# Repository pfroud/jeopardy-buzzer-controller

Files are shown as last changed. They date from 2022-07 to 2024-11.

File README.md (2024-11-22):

# Jeopardy buzzer controller

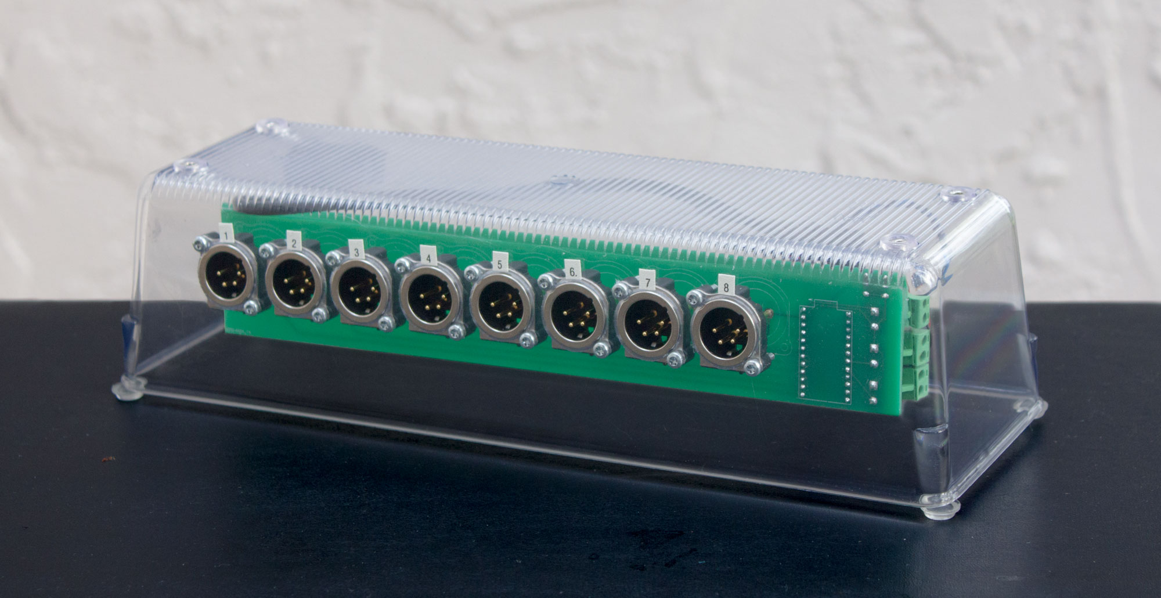
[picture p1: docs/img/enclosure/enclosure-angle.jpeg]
photo of enclosure


## About

For use with my [Jeopardy software](https://github.com/pfroud/jeopardy).

This device uses an Arduino to emulate a USB HID keyboard (like a QWERTY keyboard not a music keyboard). Instead of normal keyboard keys, the inputs come from rugged metal footswitches on long cables.

The sole purpose of this device is to convert physical button presses into USB HID keystrokes. It cannot tell which person buzzed first for a question, for example. All of that logic is done by software running on the host PC.

The PCB was designed using KiCad version 6 and fabricated by JLCPCB.

## Parts

The two most interesting parts are:

* [Sparkfun Pro Micro](https://www.sparkfun.com/products/12640) (not Mini, not Nano)
    * Informally called "Arduino Pro Micro" but it's actually a Sparkfun product which is Arduino-compatible.
    * To learn about the software running on the Arduino, see the [Arduino directory](Arduino).
* [XLR receptacle NC4MBV](https://www.neutrik.com/en/product/nc4mbv-1) to connect the buzzers.
    * To learn more, go to the "XLR connectors" section in this document.

Other parts:

* [12-pin female headers](https://www.aliexpress.us/item/2255801012106911.html) to hold the Arduino.
    * The Arduino could instead be soldered directly to the PCB if you're feeling confident.
* A toggle switch to enable/disable the Arduino software.
    * Lets you turn the buzzers off without unplugging the USB cable.
* [Panel-mount LED lights](https://www.aliexpress.com/item/3256803816108154.html) to indicate when it's powered and enabled.
* [2-pin pluggable terminal blocks](https://www.aliexpress.us/item/2251832631116561.html) to connect the toggle switch and indicator LEDs to the PCB.
* A 6mm tactile pushbutton to reset the Arduino.
    * The Pro Micro does not have a built-in reset button.

Then everything gets assembled into an [enclosure](docs/enclosure.md).

## Buzzers

On the Jeopardy TV show each contestant holds a thumb-operated buzzer ([source](https://www.jeopardy.com/jbuzz/behind-scenes/how-does-jeopardy-buzzer-work)).

My game has teams instead of individual players, so the buzzers rest on a table for access by all team members. I got rugged metal footswitches to withstand being slammed when someone thinks of an answer.

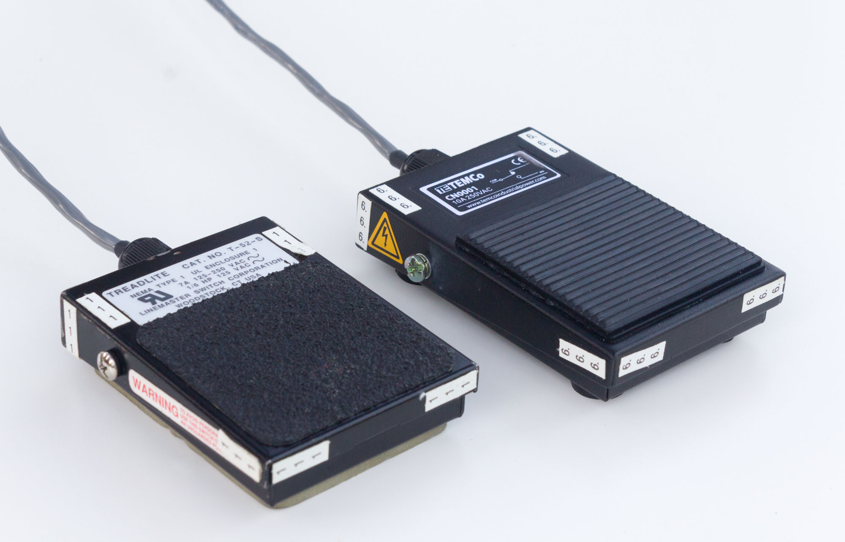
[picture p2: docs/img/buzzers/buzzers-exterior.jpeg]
Photo of two footswitches used as buzzers


I started with Treadlite footswitches from at HSC Electronics (RIP) then got some TEMCo ones from [eBay](https://www.ebay.com/itm/372481343124).

On each footswitch I had to grind down the metal housing a little to fit a [PG7 cord grip](https://www.ebay.com/itm/222727122407). (PG stands for [Panzergewinde](https://en.wikipedia.org/wiki/Panzergewinde) which is an old German thread standard inexplicably still in use.)

The Treadlite model (below left) has a seemingly-custom switch mechanism inside, while the TEMCo model (below right) has a standard limit switch. The Treadlite ones originally come with *two* switches mounted at different heights but I removed the lower ones. The cable I used has a foil shield so I connected the drain wire to the metal housing for fun.

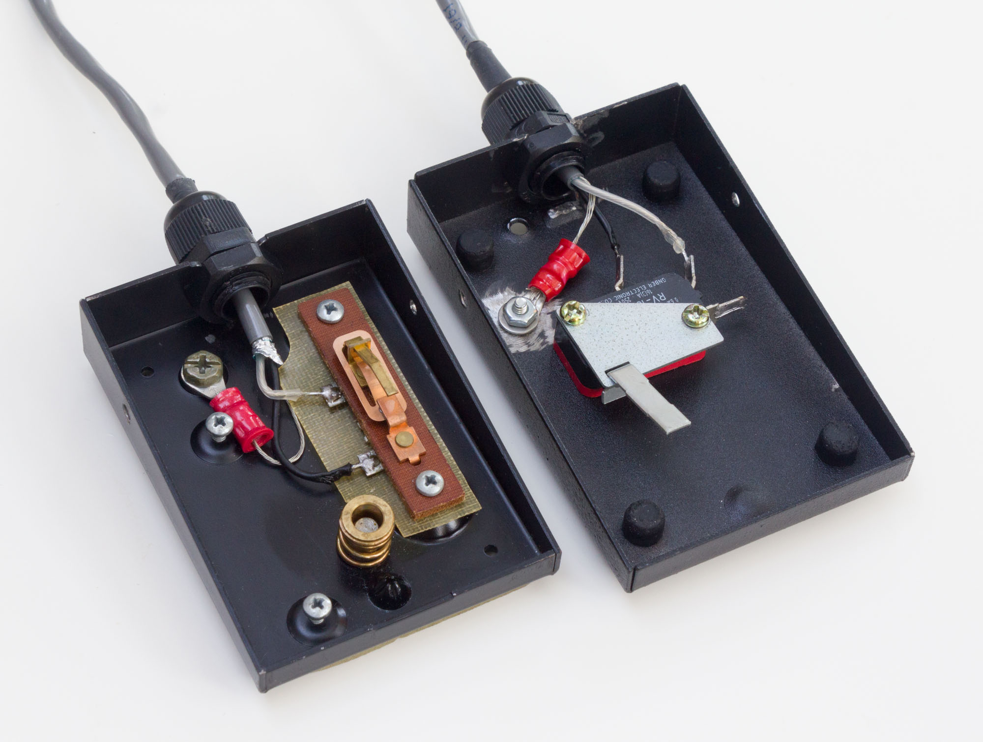
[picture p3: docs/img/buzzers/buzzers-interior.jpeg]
Photo of two footswitches with the tops removed to show the switches and wiring inside


Eight buzzers are supported although I rarely use more than six.

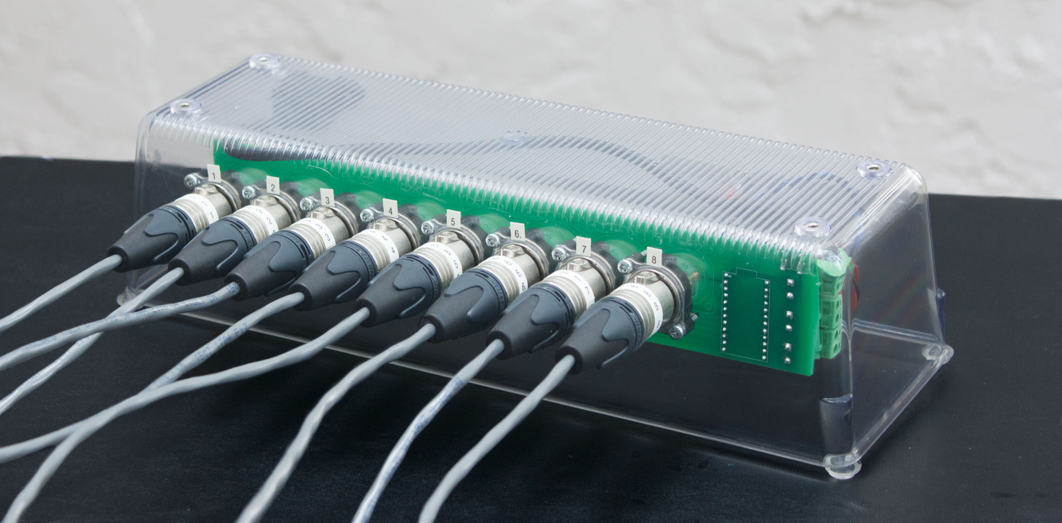
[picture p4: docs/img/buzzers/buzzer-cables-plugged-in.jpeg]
Photo of controller with eight buzzer cables plugged in


## Known bugs & future work

### PCB design

* There is no input protection on the Arduino pins.
* The trace length between the Arduino and XLR connector is different for each connector.

### Does using an HID keyboard for this make any sense??

Not really. The original scope of my [Jeopardy project](https://github.com/pfroud/jeopardy) was software only. The hardware buzzers have been gradually developed as needed. Want to keep it simple!

See docs/dont-use-a-HID-keyboard.md.

### Issues with the XLR connectors

XLR connectors are usually used in professional audio and stage lighting, so they are overkill for this application. I wanted locking connectors and found these in surplus.

#### Wasted pins

Only two out of four pins are used. In the future, the spare pins could be used for lighting or some other new feature. An overwhelming number of two-pin locking connectors are available.

#### Polarity

The polarity of the XLR connectors should be reversed.

Neutrik makes four types of 4-pin XLR connectors. Look at the table below for a visual aid.

The receptacles on the controller are male (top left, NC4MBV) which allows fingers to touch the pins, exposing the Arduino to static electricity.

Meanwhile the connectors on the buzzer cables are female (bottom right, NC4FXX). The recessed pins prevent fingers touching them, but that protection isn't needed because the buzzers contain only passive switches.

The controller should use female receptacles, and the buzzers should use male cable connectors.

<table>
<tr>
    <td></td>
    <td align="center">Male</td>
    <td align="center">Female</td>
</tr>
<tr>
    <td>Receptacle</td>
    <td align="center">
        <a href="https://www.neutrik.us/en-us/product/nc4mbv-1">
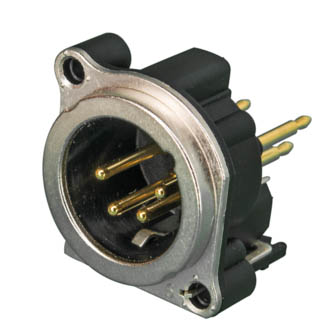
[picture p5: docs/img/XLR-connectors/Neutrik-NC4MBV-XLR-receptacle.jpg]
Neutrik NC4MBV XLR receptacle
            
            <br>
            NC4MBV
        </a>
    </td>
    <td align="center">
        <a href="https://www.neutrik.us/en-us/product/nc4fbv">
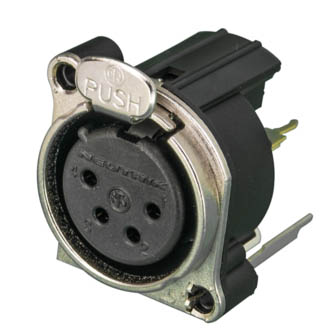
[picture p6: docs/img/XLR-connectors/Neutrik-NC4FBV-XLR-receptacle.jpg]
Neutrik NC4FBV XLR receptacle
            
            <br>
            NC4FBV
        </a>
    </td>
</tr>
<tr>
    <td>Cable connector</td>
    <td align="center">
        <a href="https://www.neutrik.us/en-us/product/nc4mxx">
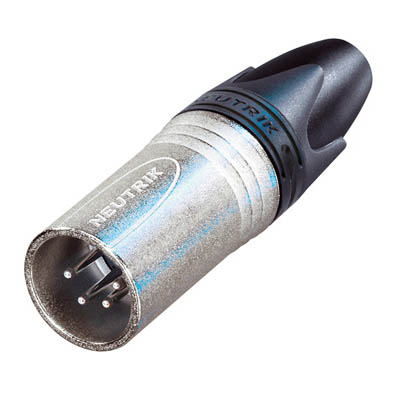
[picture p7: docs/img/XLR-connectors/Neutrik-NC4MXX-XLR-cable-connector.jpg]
Neutrik NC4MXX XLR cable connector
            
            <br>
            NC4MXX
        </a>
    </td>
    <td align="center">
        <a href="https://www.neutrik.us/en-us/product/nc4fxx">
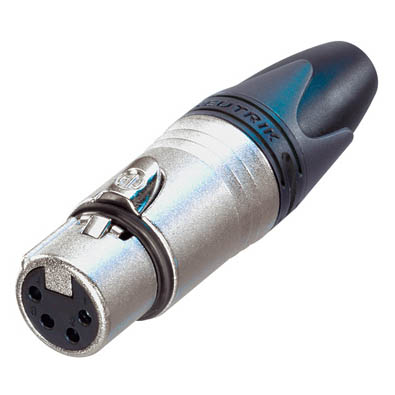
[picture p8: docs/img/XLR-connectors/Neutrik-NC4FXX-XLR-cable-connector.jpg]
Neutrik NC4FXX XLR cable connector
            
            <br>
            NC4FXX
        </a>
    </td>
</tr>
</table>

## Previous versions of my Jeopardy buzzer controller

I made my first Jeopardy buzzer controller in 2018. It used the the PCB from an off-the-shelf USB keyboard (a QWERTY keyboard not a music keyboard) to convert physical button presses into USB HID keystrokes.

Inside the case of a broken power tool battery charger was a tangle of wires and Wago lever nuts. I used barrel jacks intended for DC power to connect the buzzers because they were easily available. This worked acceptably well but looked crazy:

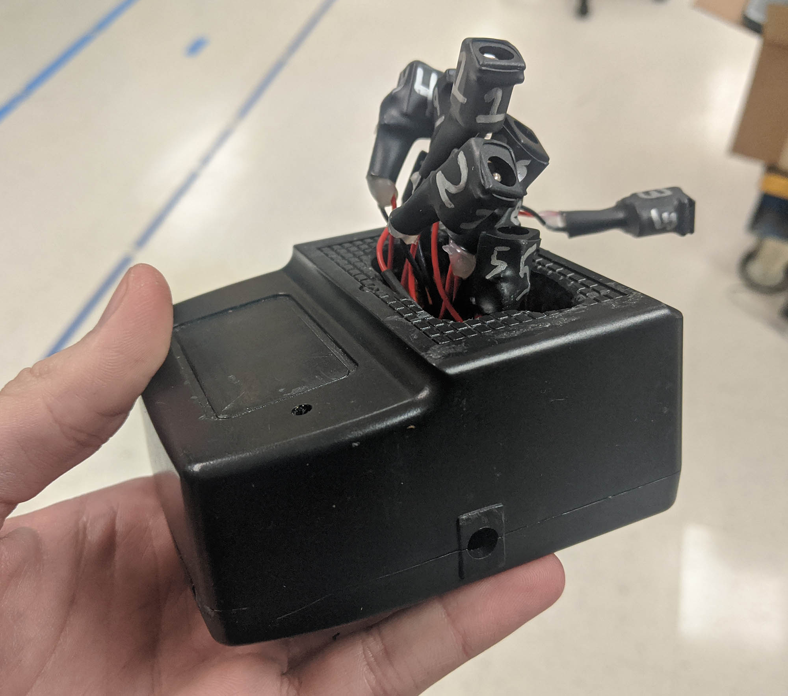
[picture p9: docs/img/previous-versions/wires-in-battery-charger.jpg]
Photo of several wires coming out of a handheld black plastic box


In 2020 re-did the enclosure and wiring but kept using barrel jacks:

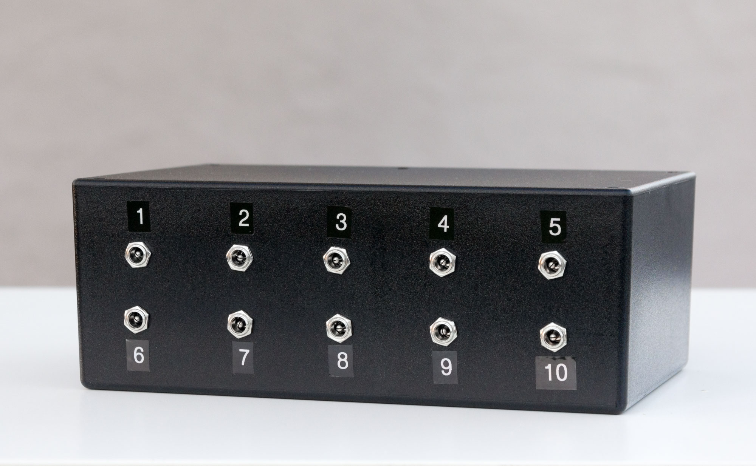
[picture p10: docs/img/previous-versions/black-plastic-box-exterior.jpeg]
Photo of the outside of a black plastic box with ten connectors on the front


Inside the new enclosure, I upgraded to a prototype board and pluggable wire-to-board connectors. The USB keyboard PCB is visible on the left:

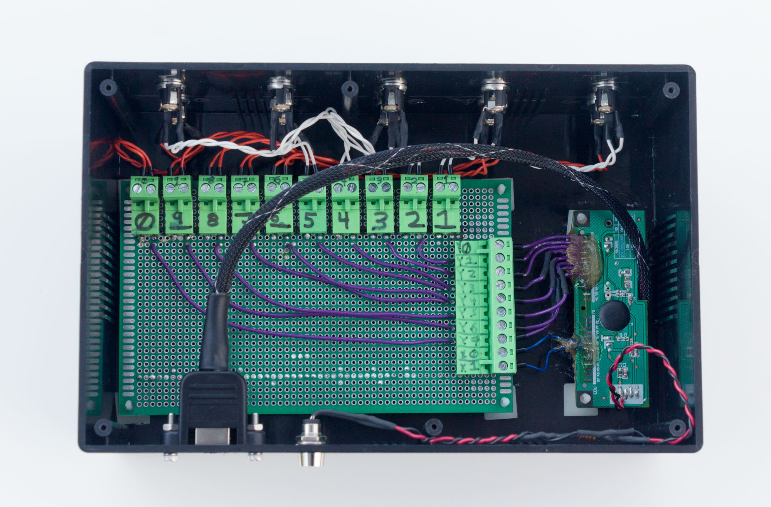
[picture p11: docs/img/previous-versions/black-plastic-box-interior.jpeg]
Photo of the inside of the black plastic box showing two circuit boards and a bunch of wires and connectors


In 2022 I re-did the whole thing with a custom PCB and Arduino (which is this repository).

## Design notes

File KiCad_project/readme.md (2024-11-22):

# KiCad project

Pictures of the PCB:

<table>
<tr>
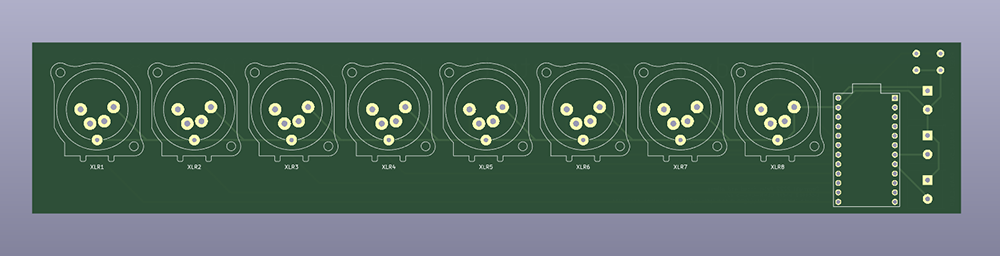
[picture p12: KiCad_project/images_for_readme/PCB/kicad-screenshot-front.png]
Screenshot of front of PCB in KiCad
<td></td>
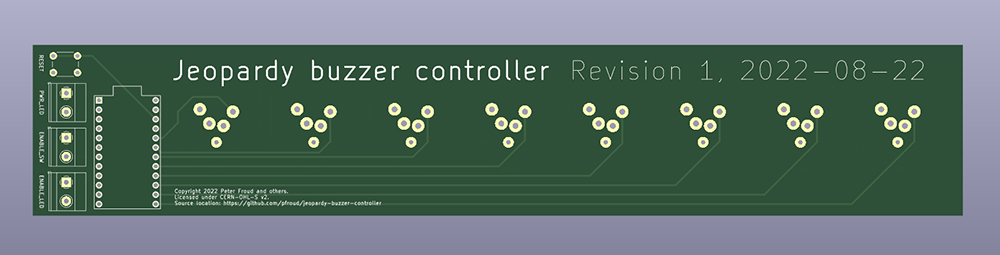
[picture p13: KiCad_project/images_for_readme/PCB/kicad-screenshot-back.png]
Screenshot of back of PCB in KiCad
<td></td>
</tr>
<tr>
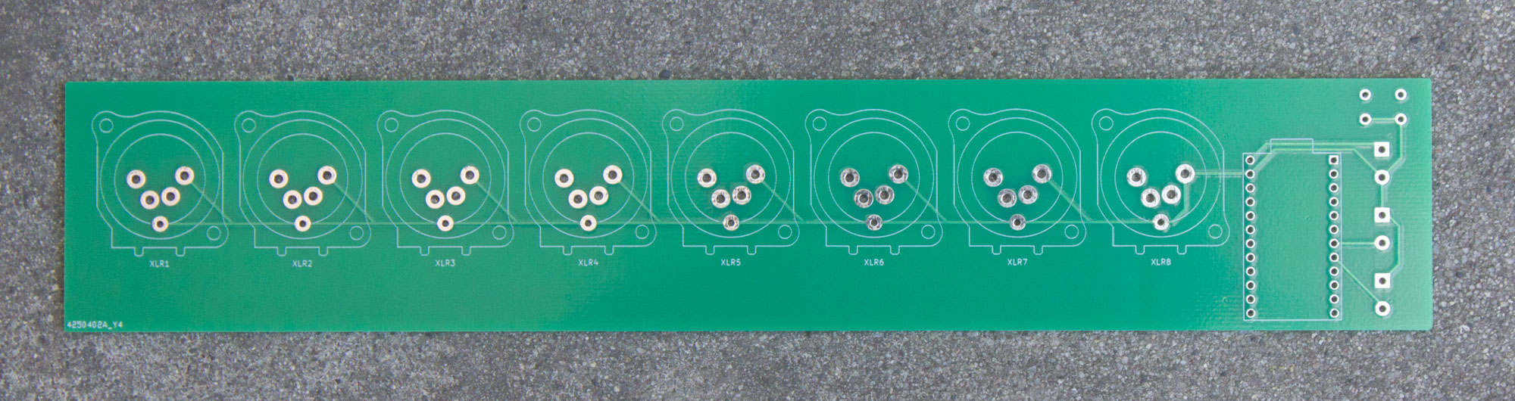
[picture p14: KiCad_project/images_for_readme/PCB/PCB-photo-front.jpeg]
Photo of front of PCB
<td></td>
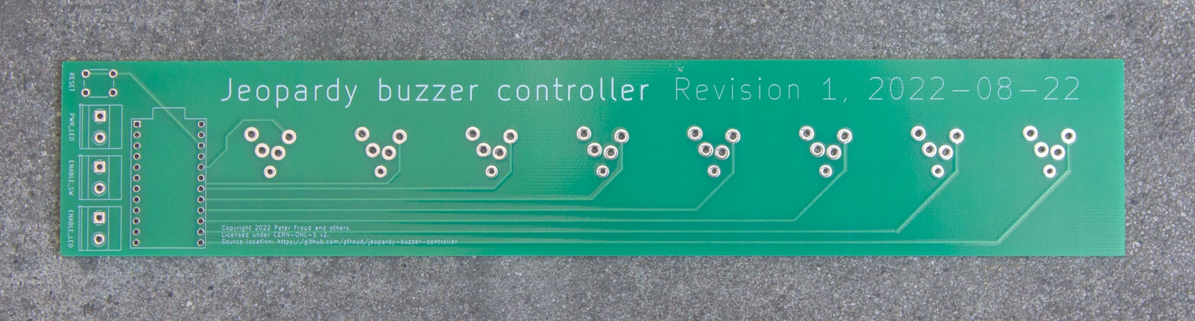
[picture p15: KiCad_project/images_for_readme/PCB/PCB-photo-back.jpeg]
Photo of back of PCB
<td></td>
</tr>
</table>

Only eight buzzers are supported and the Arduino has twelve digital I/O pins, so no [matrix circuit](https://en.wikipedia.org/wiki/Keyboard_matrix_circuit) is needed.

## Schematic screenshots

Here are screenshots of the schematic so you don't need to download / install / launch KiCad:

<table>
<tr>
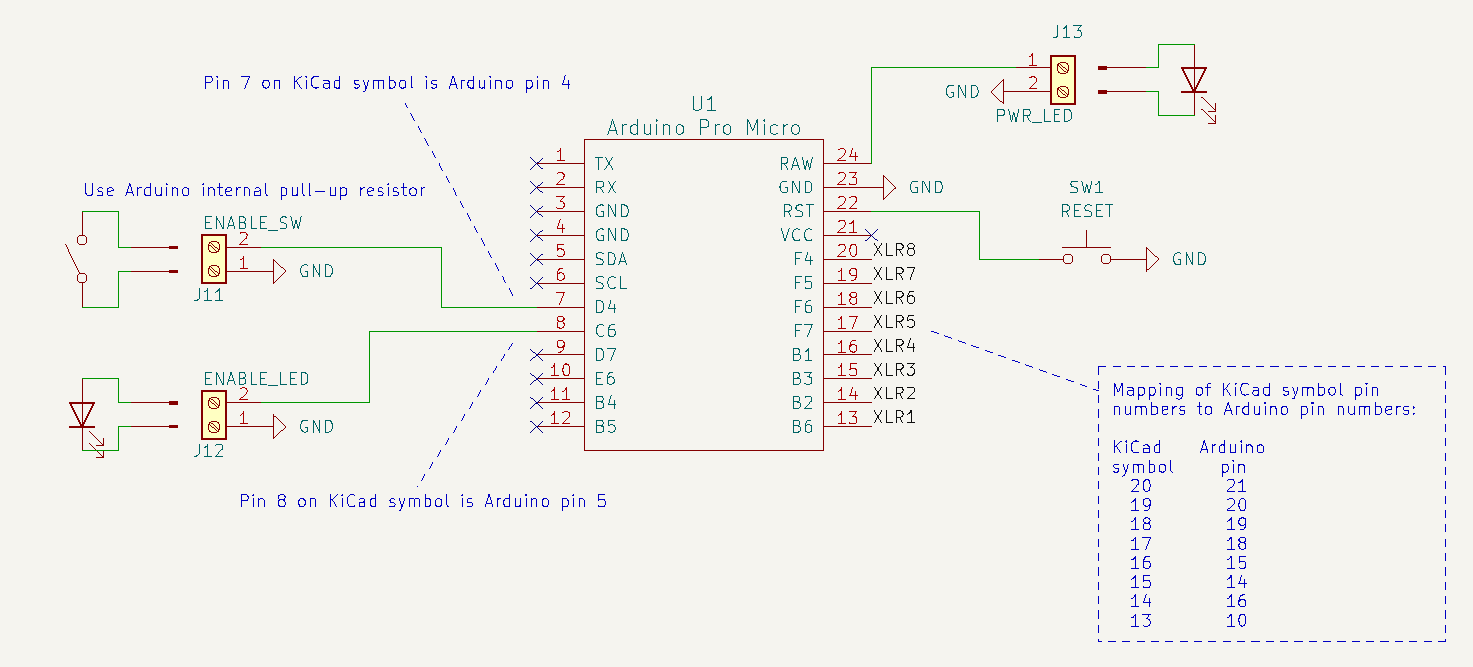
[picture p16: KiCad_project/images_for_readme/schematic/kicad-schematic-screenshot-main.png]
Screenshot of schematic showing the Arduino, power indicator light, reset button, enable switch, and enable indicator light
<td></td>
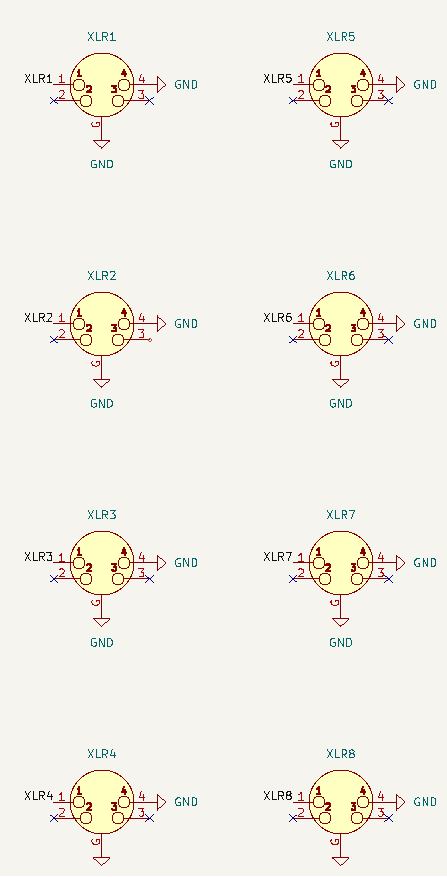
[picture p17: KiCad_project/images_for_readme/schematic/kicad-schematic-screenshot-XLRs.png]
Screenshot of the schematic showing the XLR connectors
<td></td>
</tr>
</table>

## XLR connector

They are [Neutrik NC4MBV](https://www.neutrik.com/en/product/nc4mbv-1) which are:

> 4 pole male XLR receptacle, grounding: separate ground contact to mating connector shell and front panel.

Each connector has four cylindrical pins with shoulders. A rectangular tab on the bottom contacts the shell of the mating connector.

<p align="center">
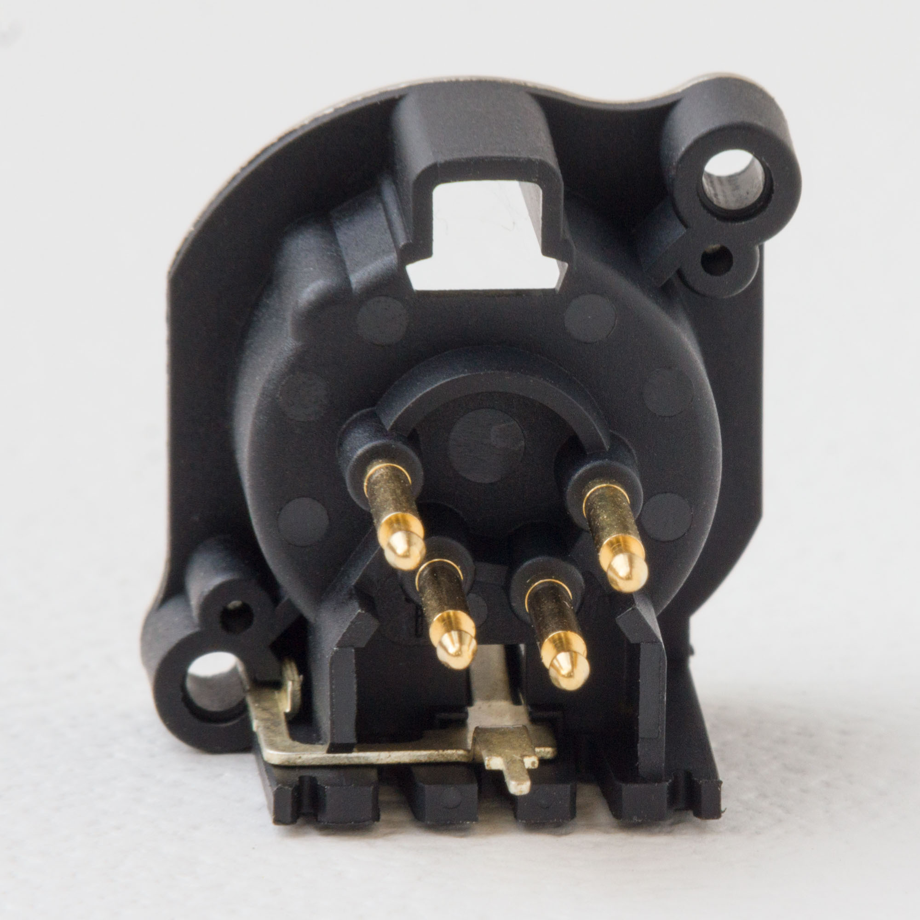
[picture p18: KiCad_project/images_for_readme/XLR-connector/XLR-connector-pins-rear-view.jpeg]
Photo of the back of an XLR connector, showing cylindrical pins and one rectangular tab.

</p>

KiCad comes with symbols & footprints for 4-pin XLR connectors; I modified both slightly.

### Symbol

I added a ground pin to the "XLR4" symbol in the KiCad [Connector](https://kicad.github.io/symbols/Connector) library:

<p align="center">
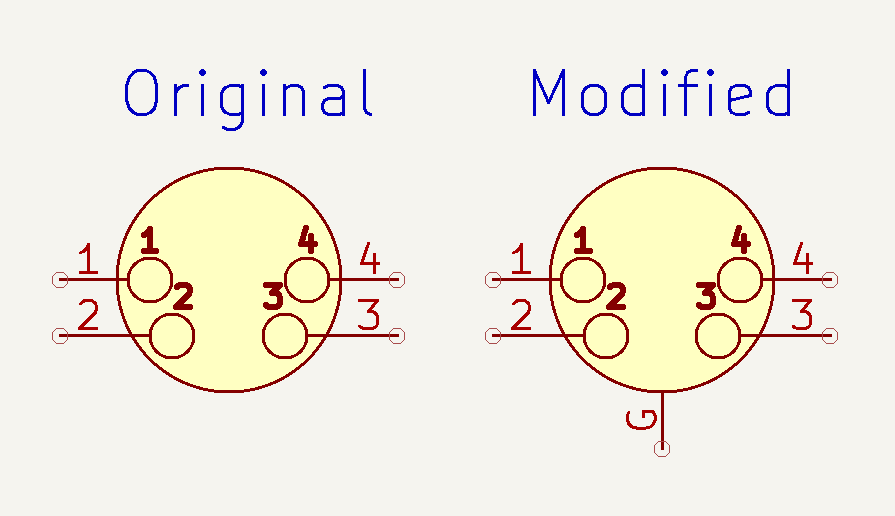
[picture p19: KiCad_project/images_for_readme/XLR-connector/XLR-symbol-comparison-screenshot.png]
Screenshot of two XLR schematic symbols, one has a ground pin added.

</p>

### Footprint

I started with the "Jack_XLR_Neutrik_NC4MBV_Vertical" footprint in the KiCad [Connector_Audio](https://kicad.github.io/footprints/Connector_Audio) library, which  exactly matches the footprint provided by Neutrik.

After the PCB was fabricated, I saw that those dimensions hold the connector about  &frac14; inch (6 mm) above the board. The shoulders of the cylindrical pins and the square section of the ground tab both rest on the PCB surface. I think this looks sort of silly and expected the black plastic housing to touch the board.

To see a comparison, I drilled out the pads on an extra board. In the pictures below, the original footprint is on the left and the footprint with drilled-out holes is on the right:

<table>
<tr>
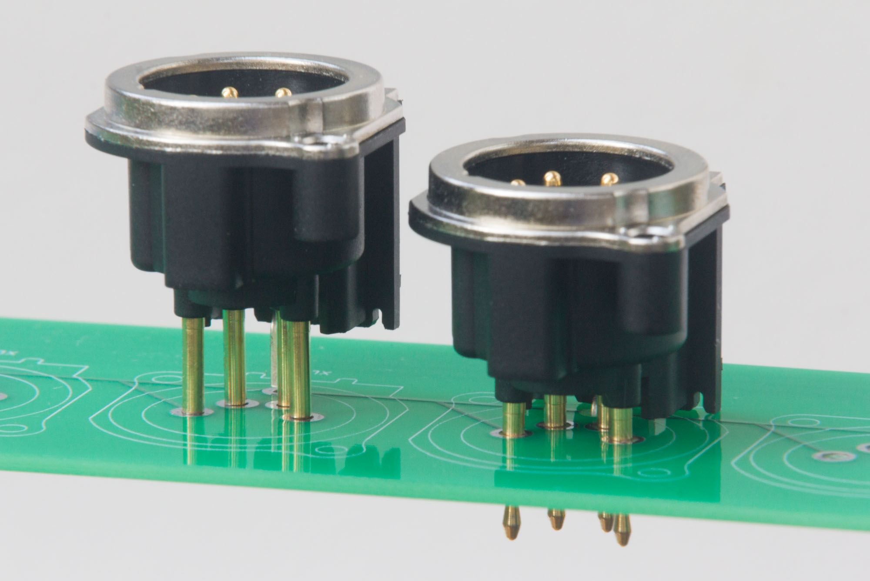
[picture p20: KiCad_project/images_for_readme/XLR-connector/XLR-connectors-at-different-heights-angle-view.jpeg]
Photo of two XLR connectors mounted on PCB at different heights
<td></td>
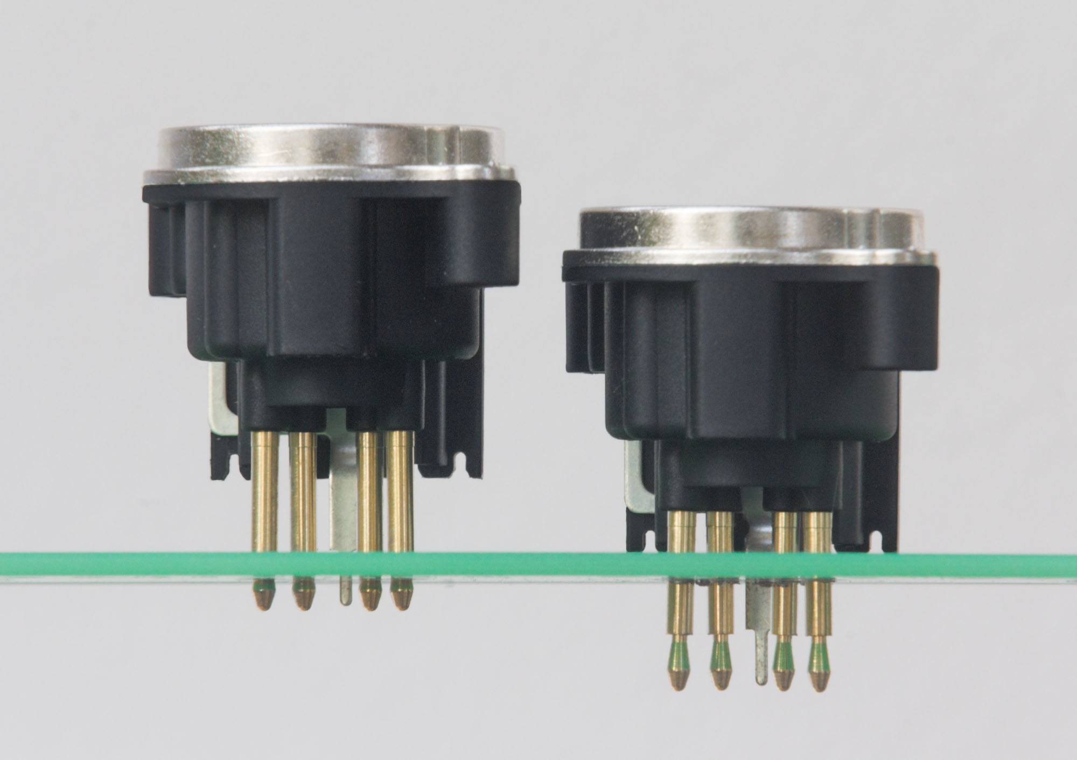
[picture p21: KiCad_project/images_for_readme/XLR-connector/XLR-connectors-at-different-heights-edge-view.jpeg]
Photo of two XLR connectors mounted on PCB at different heights
<td></td>
</tr>
</table>

I edited the footprint to make the black plastic housing touch the PCB. First I increased the sizes of pads 1-4 so the full diameter of the cylinder could go through the board. Then I changed the ground pin from a circle to a slot to let the bigger non-square part of the ground tab go through as well.

<p align="center">
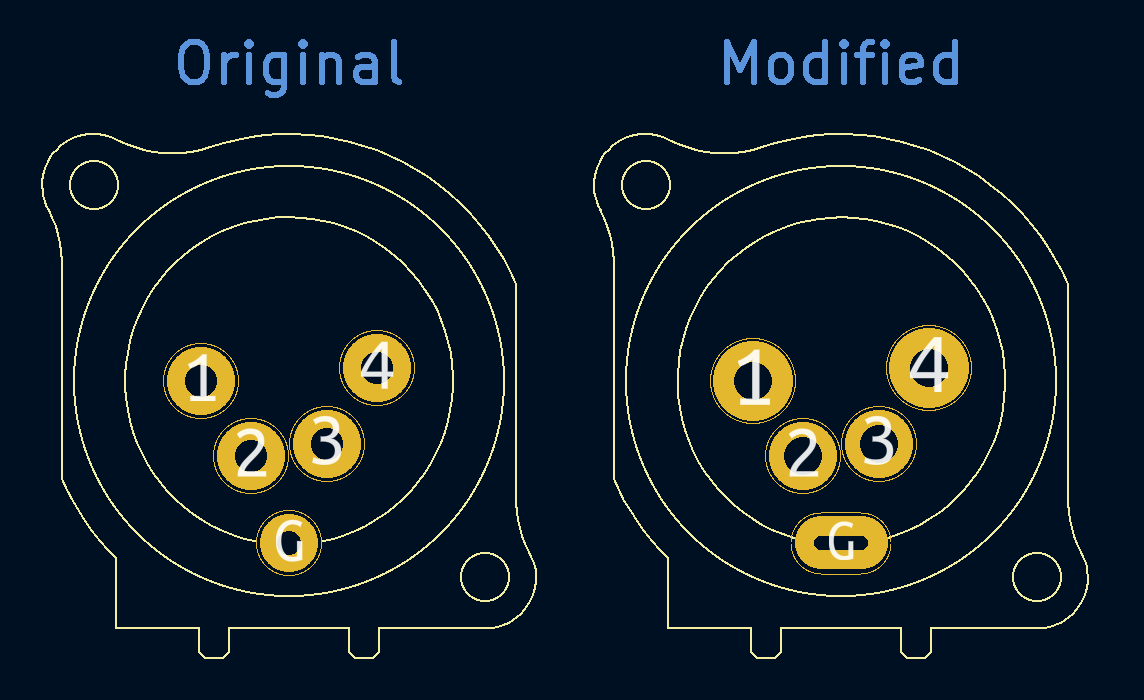
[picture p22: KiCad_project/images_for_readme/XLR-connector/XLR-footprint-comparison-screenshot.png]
Screenshot of two XLR footprints

</p>

But I never got a board fabricated with the modified footprint! When assembling the PCB into the [enclosure](../docs/enclosure.md), I discovered that having the connectors on long legs was actually very helpful because they could bend slightly to accommodate imperfect hole alignment in the plastic wall.

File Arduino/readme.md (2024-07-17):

# Arduino software

It uses the [HID keyboard library](https://www.arduino.cc/reference/en/language/functions/usb/keyboard/).

For details about how set up your board see [setup-instructions.md](setup-instructions.md).

Only eight buzzers are supported and the Arduino has twelve digital I/O pins, so no [matrix circuit](https://en.wikipedia.org/wiki/Keyboard_matrix_circuit) is needed.

## Supported hardware

Not all Arduino boards can be used because the keyboard library requires a microcontroller with built-in USB support. For example, the Arduino Uno and Mega have a separate chip to do USB communication which doesn't let us do HID keyboard.

This project uses an [Sparkfun Pro Micro](https://www.sparkfun.com/products/12640) (informally called "Arduino Pro Micro"). It has ATmega32U4 chip which has USB built-in!

## KiCad symbol pin vs Arduino pin number

The KiCad symbol & footprint are from the [ProMicroKiCad](https://github.com/Biacco42/ProMicroKiCad) repository by GitHub user Biacco42. The pin numbering in the KiCad symbol starts at one and increases by one for each pin.

To use the Arduino [`digitalRead()`](https://www.arduino.cc/reference/en/language/functions/digital-io/digitalread/) function we need to know the "Arduino pin number". According to the [SparkFun Pro Micro Hookup  Guide](https://learn.sparkfun.com/tutorials/pro-micro--fio-v3-hookup-guide#hardware-overview-pro-micro), the Arduino pin numbers are discontinuous and not monotone.

<table>
<tr>
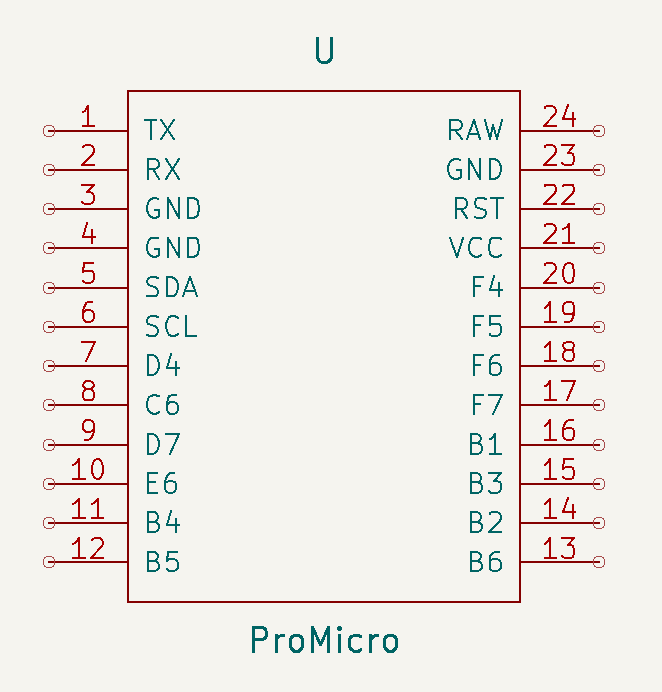
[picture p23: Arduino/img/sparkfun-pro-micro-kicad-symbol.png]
Sparkfun Pro Micro KiCad symbol
<td align="center"><br>KiCad symbol</td>
Sparkfun Pro Micro pinout
<td align="center"><br>Arduino pin numbers</td>
</tr>
</table>

Here's a a table to cross-reference the pin numbers (excluding RX, TX, RAW, GND, and VCC):

| KiCad<br>symbol | Arduino<br>pin  | &emsp;&emsp; | KiCad<br>symbol | Arduino<br>pin |
| --- | --- | --- | --- | --- |
| 5 | 2 | &emsp;&emsp; | 20 | 21 |
| 6 | 3 | &emsp;&emsp; | 19 | 20 |
| 7 | 4 | &emsp;&emsp; | 18 | 19 |
| 8 | 5 | &emsp;&emsp; | 17 | 18 |
| 9 | 6 | &emsp;&emsp; | 16 | 15 |
| 10 | 7 | &emsp;&emsp; | 15 | 14 |
| 11 | 8 | &emsp;&emsp; | 14 | 16 |
| 12 | 9 | &emsp;&emsp; | 13 | 10 |

## Debouncing

Contacts in a mechanical switch bounce when actuated, which makes the signal appear to be repeatedly opening/closing. [Debouncing](https://en.wikipedia.org/wiki/Keyboard_technology#Debouncing) waits for the signal to settle before deciding if the switch moved.

The debouncing logic is from an Arduino example, which is accessible [online](https://docs.arduino.cc/built-in-examples/digital/Debounce) and in the Arduino software from File > Examples > 02.Digital > Debounce.

I measured the settling time for both brands of footswitches I'm using then chose 5 milliseconds debounce time.

<table>
<tr>
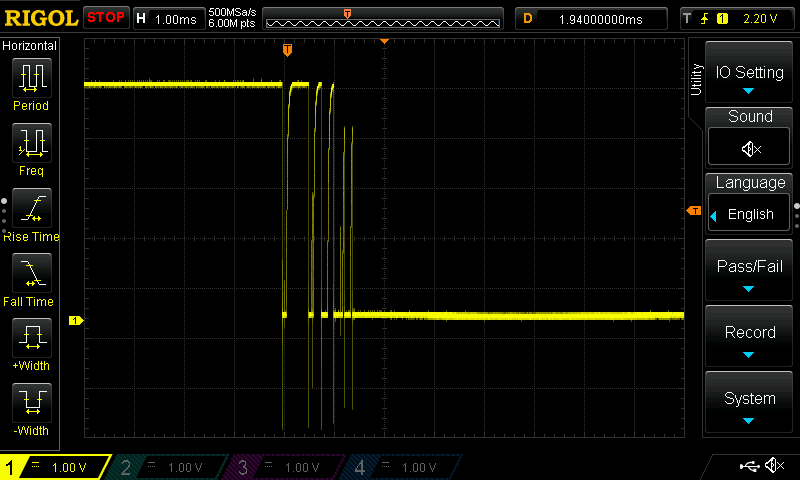
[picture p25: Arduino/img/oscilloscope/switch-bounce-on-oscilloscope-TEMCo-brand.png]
Oscilloscope trace show switch bounce
<td align="center"><br>TEMCo</td>
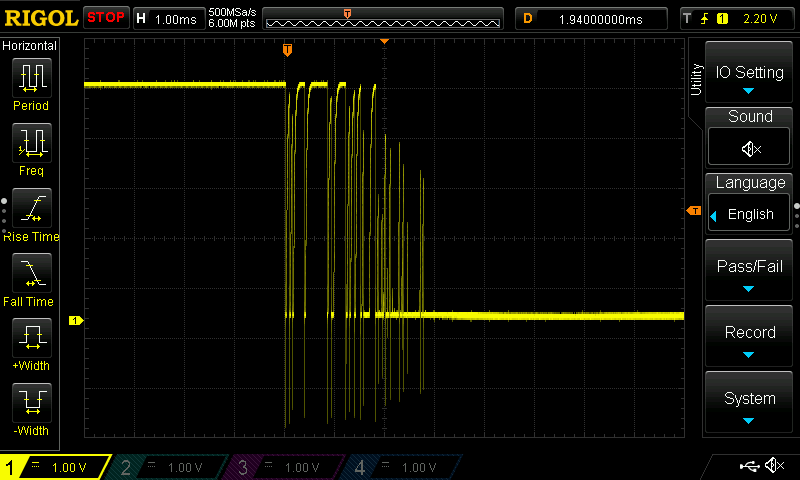
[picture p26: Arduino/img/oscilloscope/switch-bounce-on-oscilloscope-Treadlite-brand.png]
Oscilloscope trace showing switch bounce
<td align="center"><br>Treadlite</td>
</tr>
</table>

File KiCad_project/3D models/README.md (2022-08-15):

# Where the 3D models came from

## Arduino Pro Micro

File "sparkfun_pro_micro.x3d" from [kicad-lib-arduino by g200kg on GitHub](https://github.com/g200kg/kicad-lib-arduino/blob/main/Arduino.3dshapes/sparkfun_pro_micro.x3d) , CC0 license.

## Pluggable terminal block

File "2EDGV-5.08-02P-14-00AH.STEP" from [DEGSON 2EDG Series 5.08mm pluggable terminal block pack by Sig Elso on GrabCAD](https://grabcad.com/library/degson-2edg-series-5-08mm-pluggable-terminal-block-pack-1/details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). See GrabCAD help article [How can models be used and shared?](https://help.grabcad.com/article/246-how-can-models-be-used-and-shared)

Modified by Peter Froud on July 20th 2022. I opened the STEP file in FreeCAD and then re-exported it to STEP without making any changes, which reduced the file size from 2.2 MB to 1.3 MB.

## XLR connector

File "Neutrik_NC4MBV.stp" from https://www.neutrik.com/en/product/nc4mbv-1. No license information availabe but I asume they want you to use it.

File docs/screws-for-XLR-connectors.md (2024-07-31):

# Screws for XLR connectors

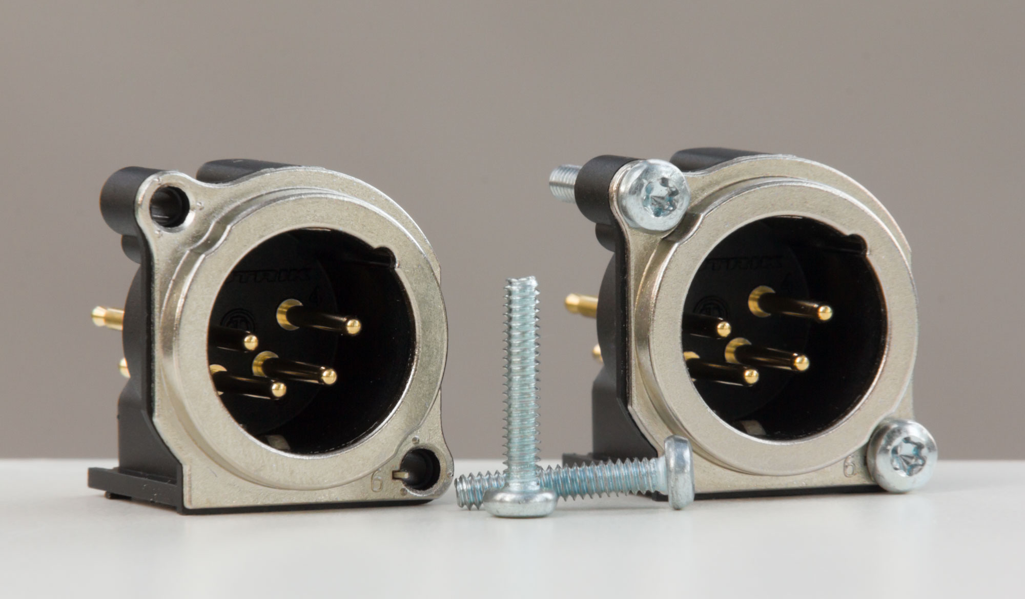
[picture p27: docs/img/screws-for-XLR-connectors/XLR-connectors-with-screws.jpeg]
Photo of XLR connectors with screws


Each XLR receptacle has two holes for screws. The Neutrik website said to use [B-SCREW-1-8](https://www.neutrik.com/en/product/b-screw-1-8) which is:

> Selftapping TAPTITE® screw M2.5 DIN 7500

What does that mean??

* TAPTITE is a brand name.
* M2.5 is the thread size.
* DIN 7500 is a standard for trilobular thread-forming screws.

At the time of writing B-SCREW-1-8 were available [from Mouser](https://www.mouser.com/ProductDetail/Neutrik/B-SCREW-1-8?qs=sGAEpiMZZMsqIr59i2oRcnT%2FsgA0IPpvi2IDCmGJBT0%3D) for US$0.28 each plus $8 shipping.

I didn't think I needed to get their special brand-name screws, but it turns out that wouldn't been easier than the path I took.

First I tried regular #4-40 machine screws which I already had on hand. They made a secure hold but needed more torque than comfortably transferrable with the Phillips head. Some of the screw heads began to deform and strip.

Next I ordered [M2.5 machine screw with Torx drive](https://www.aliexpress.us/item/3256803033727043.html) (non thread-forming). Although they were the same thread size as the Neutrik screws, the diameter was slightly too small to make a secure hold. Fifty pieces cost US$1.09 shipped.

Then I found [#4-40 machine screws with Torx drive](https://www.fastenal.com/product/details/0143903) at Fastenal. The 5/8-inch length were on sale for US$0.0039 (0.39¢) each!!!

<!-- Use one-cell table to add border around image -->
<table align="center"><tr><td>
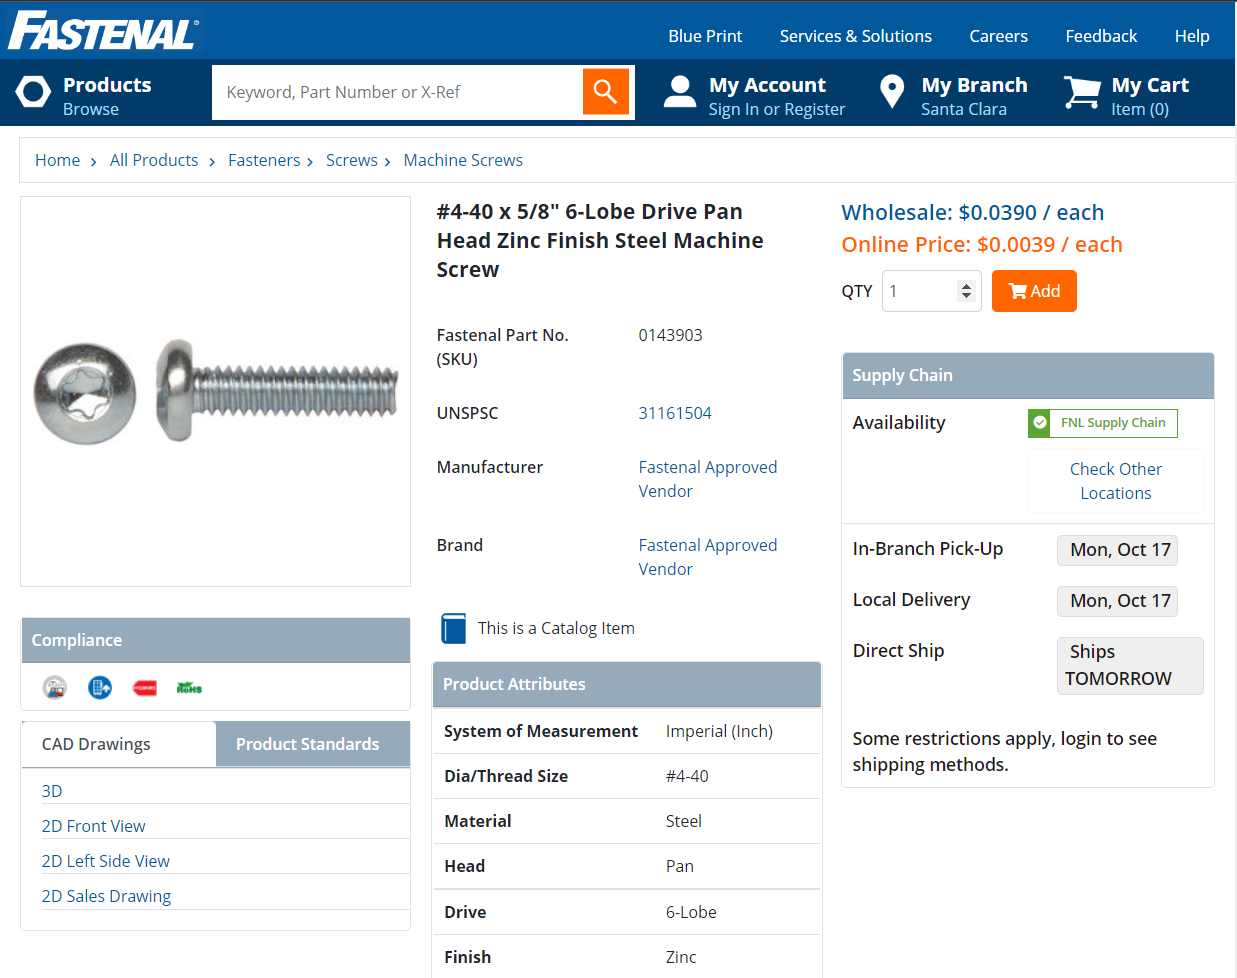
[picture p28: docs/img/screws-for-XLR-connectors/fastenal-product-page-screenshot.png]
Screenshot of Fastenal product page for machine screws, showing the price of 0.39 cents each

</td></tr></table>

Amusingly, the price was rounded down and displayed as "$0.00" in the table of search results:

<table align="center"><tr><td>
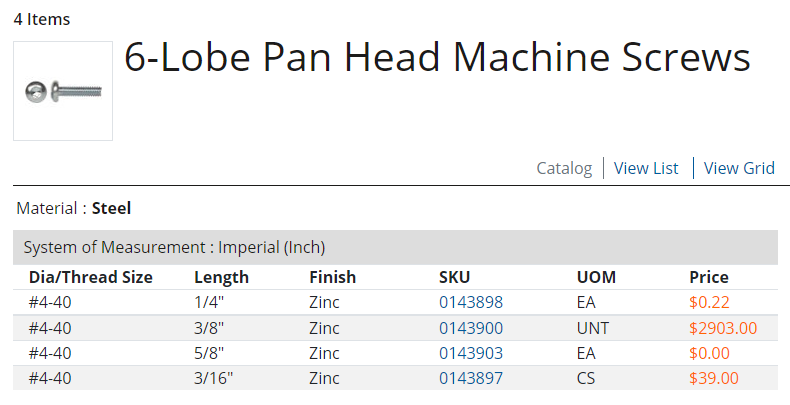
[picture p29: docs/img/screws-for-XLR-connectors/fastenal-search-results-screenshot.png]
Screenshot of Fastenal search results page where the price for a row is $0.00

</td></tr></table>

I ordered 200 pieces for US$0.78 total. Shipping was US$12. These screws work well and the Torx head is pleasant to use.

5/8 inches is longer than necessary. The 1/4-inch length screws would've worked but they cost US$0.2214 each, which is more than 50 (fifty) times the price of 5/8-inch length!

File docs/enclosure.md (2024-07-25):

# Enclosure for Jeopardy buzzer controller

<table>
<tr>
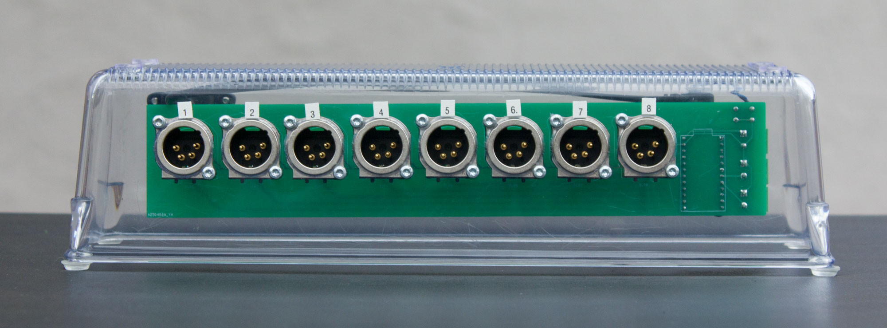
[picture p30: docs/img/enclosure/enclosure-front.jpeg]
Front of Jeopardy enclosure
<td></td>
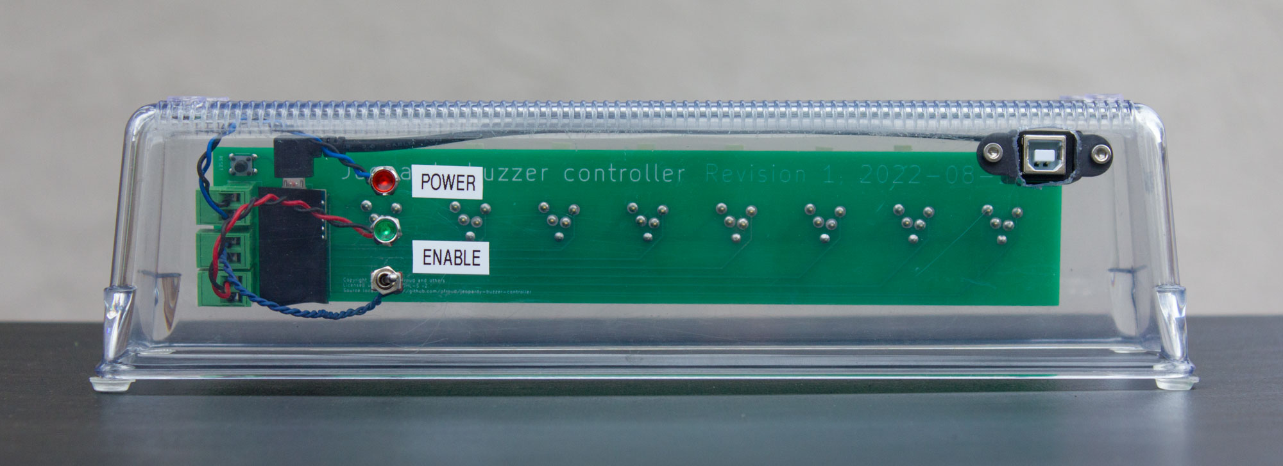
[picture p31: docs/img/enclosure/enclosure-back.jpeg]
Back of enclosure
<td></td>
</tr>
<tr>
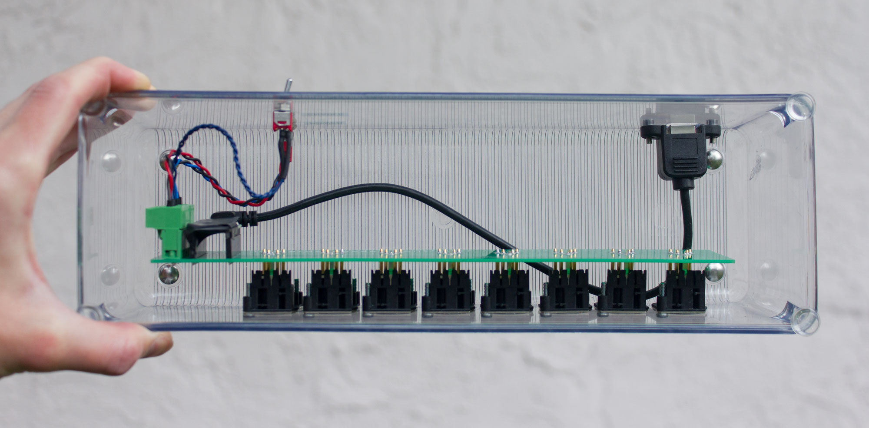
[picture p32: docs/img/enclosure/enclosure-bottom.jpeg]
Bottom of enclosure
<td></td>
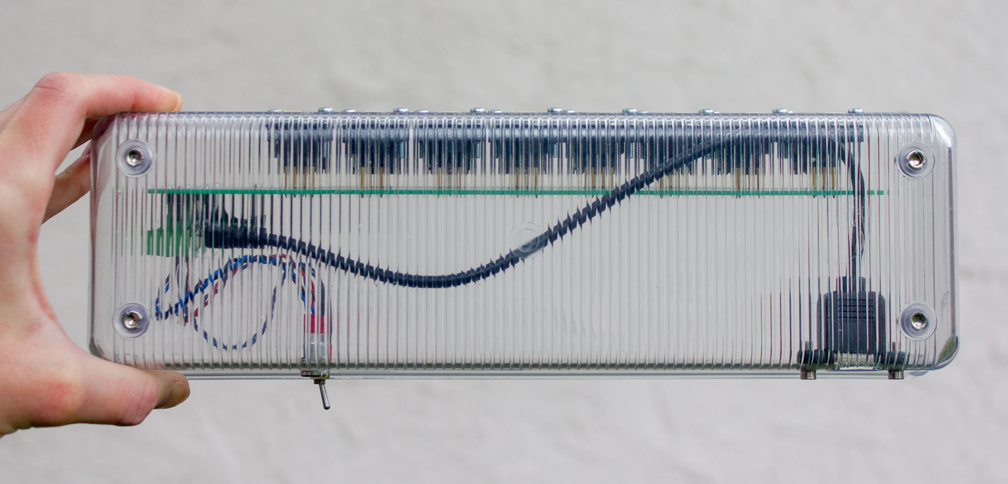
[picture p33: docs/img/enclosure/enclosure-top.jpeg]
Top of enclosure
<td></td>
</tr>
<tr>
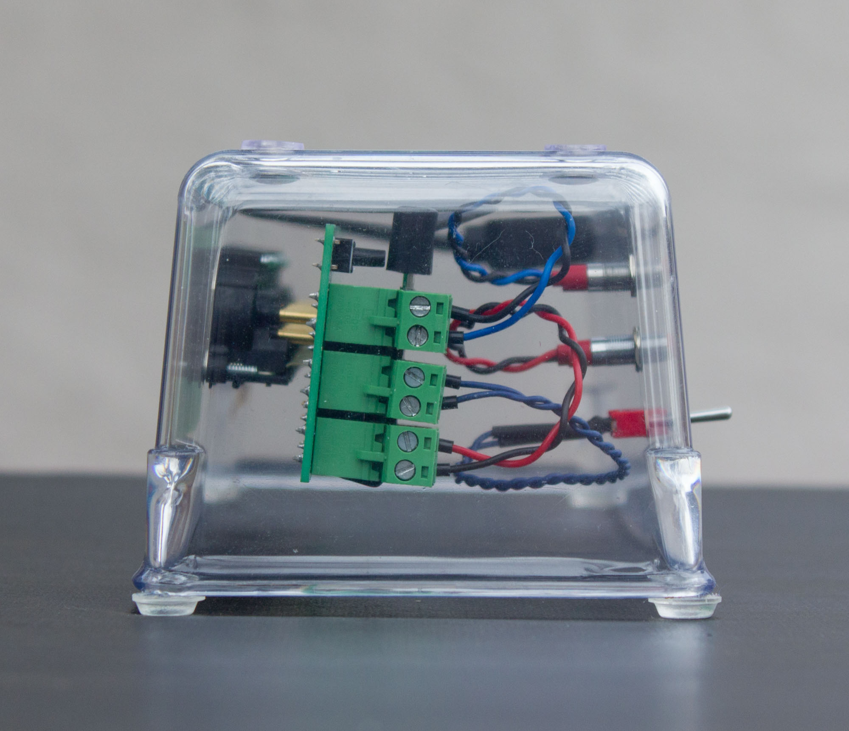
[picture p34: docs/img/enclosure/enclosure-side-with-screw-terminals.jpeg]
Side of enclosure with screw terminals visible
<td align="center"></td>
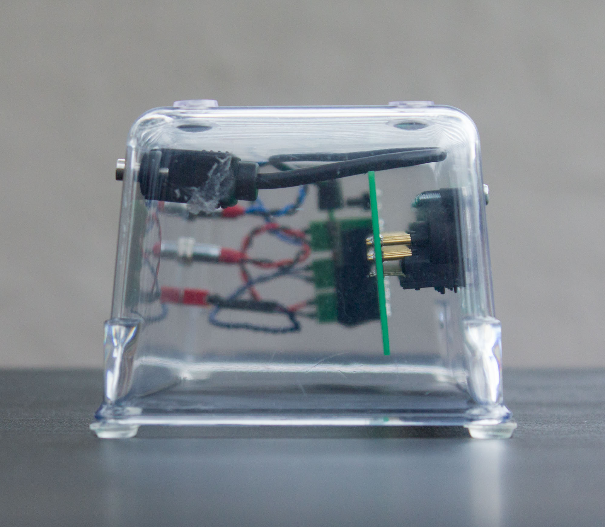
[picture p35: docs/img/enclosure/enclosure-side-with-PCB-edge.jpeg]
Side of enclosure with PCB edge visible
<td align="center"></td>
</tr>
</table>

Originally I wanted a box with a lid but couldn't find one of suitable size. It turns out an open-top box turned upside-down works really well.

3D-printing may have been sensible but I didn't want layer lines, didn't want to deal with calibrating dimensions, and didn't have access to a machine with big enough print bed.

Parts:

* [Clear plastic drawer organizer](https://www.acehardware.com/departments/storage-and-organization/bath-and-kitchen/drawer-organizers/6134167).
* [Micro-USB to panel-mount USB-B cable](https://www.aliexpress.com/item/2251832817988682.html).
* Screws to mount the XLR connectors - this was a bit of a journey so I wrote a [separate document](screws-for-XLR-connectors.md) about it!

Using a transparent enclosure is weird, but being able to see through the walls was very helpful for lining up holes.

Only the XLR connectors is directly connected to the plastic wall. The PCB is light enough to hang:

<!-- https://mermaid.js.org/syntax/flowchart.html#links-between-nodes -->

```mermaid
graph LR
wall[Plastic wall] -- Screws --- xlr[XLR connectors]  -- Solder --- PCB;
```

## Drilling holes

To make holes for the XLR connectors, I glued a template to the enclosure then used a 7/8-inch step drill bit. The template included several concentric circles to show when a hole began going off center or out of round. Lastly I cleaned up the edges with a manual deburring tool.

<table>
<tr><td>Plastic box with paper template for holes glued on</td></tr>
<tr><td>Plastic box with paper template and small holes</td></tr>
<tr><td>Plastic box with paper template and large holes</td></tr>
</tr>
</table>

## Previous tries making an enclosure

My first idea for an enclosure was a scrap of square plastic downspout:

Photo of XLR connectors in white plastic square tube

There were a few problems:

* Difficult to access the inside from the ends.
* Not enough room to attach the panel-mount USB-B connector.
* The walls flexed when drilling holes, which made the holes inaccurate and ugly.

Next I got a [wooden box](https://www.michaels.com/12in-wooden-box-by-artminds/10627739.html) which had lots of room, but was unusable because the wood splintered and broke so much.

Photo of XLR connectors in wood box, with paper template still attached

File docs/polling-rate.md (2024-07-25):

# Polling rate

This is a deep dive into the poll rate.

Polling rate is how fast the host PC queries the keyboard for inputs.

## Introduction

The keyboard tells the host PC what polling rate to use.

Excerpt from the [Endpoint Descriptors section](https://beyondlogic.org/usbnutshell/usb5.shtml#EndpointDescriptors) from USB in a Nutshell by Craig Peacock:

<blockquote>

| Offset | Field | Size | Value  | Description |
| --- | --- | ---- | --- | --- |
| 6 | bInterval | 1 | Number | Interval for polling endpoint data transfers. Value in frame counts. It may range from 1 to 255 for interrupt endpoints. |

* ***bInterval*** *is used to specify the polling interval of certain transfers. The units are expressed in frames, thus this equates to either 1ms for low/full speed devices and 125us for high speed devices.*

</blockquote>

Peacock writes the units are "1ms for low/full speed devices and 125us for high speed devices". What do those speed words mean?? From [Wikipedia]( https://en.wikipedia.org/wiki/USB_communications#Signaling_rate_(transmission_rate) ):

<table>
    <tr><th>Standard</th><th>Name</th><th>Signalling rate</th></tr>
    <tr><td rowspan="2">USB 1.0</td><td>Low Speed</td><td>1.5 megabit/sec</td></tr>
    <tr><td>Full Speed</td><td>12 megabit/sec</td></tr>
    <tr><td>USB 2.0</td><td>High Speed</td><td>480 megabit/sec</td></tr>
</table>

The Pro Micro uses Full speed so the intervals are in 1 millisecond frames. (The software below shows what speed the keyboard uses.)

## Definition in Arduino keyboard library

The USB HID endpoint is created in [HID.cpp](https://github.com/arduino/ArduinoCore-avr/blob/63092126a406402022f943ac048fa195ed7e944b/libraries/HID/src/HID.cpp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):

```C++
HIDDescriptor hidInterface = {
    D_INTERFACE(pluggedInterface, 1, USB_DEVICE_CLASS_HUMAN_INTERFACE, HID_SUBCLASS_NONE, HID_PROTOCOL_NONE),
    D_HIDREPORT(descriptorSize),
    D_ENDPOINT(USB_ENDPOINT_IN(pluggedEndpoint), USB_ENDPOINT_TYPE_INTERRUPT, USB_EP_SIZE, 0x01)
};
```

The `D_ENDPOINT` macro is defined in [USBCore.h](https://github.com/arduino/ArduinoCore-avr/blob/63092126a406402022f943ac048fa195ed7e944b/cores/arduino/USBCore.h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):

```C++
#define D_ENDPOINT(_addr,_attr,_packetSize, _interval) \
    { 7, 5, _addr,_attr,_packetSize, _interval }
```

The last parameter is the `_interval`, which is set to `0x01`. The units are one-millisecond frames so the polling rate is 1000 Hz.

## Measuring the polling rate

We can use a [scan rate estimator](https://xeonmc-archive.github.io/mkbratetools/scanrate/) tool and the Arduino sketch below to see the minimum time a key can be down for.

```C++
#include "Keyboard.h"
void setup() {
    Keyboard.begin();
}
void loop() {
    Keyboard.press('a');
    Keyboard.release('a');
    delay(2000);
}
```

Yes we are using a scan rate estimator for the polling rate. The webpage confirms:

> The *scan rate* of a keyboard measures how frequently the keyboard updates (internally) the state of its key matrix.... Note that scan rate is **not** the same as poll rate. On a USB device, *poll rate* refers to how often the OS will check the USB device for updates. The poll rate together with the scan rate determines the maximum input latency.

This device does not have a [matrix circuit](https://en.wikipedia.org/wiki/Keyboard_matrix_circuit) so the scan rate is extremely high. Assuming the scan period is zero, I think this tool lets us measure the poll rate.

Javascript keyboard events have millisecond precision. Due to rounding or aliasing or something, some of the keypresses reportedly zero milliseconds!

<!-- Use one-cell table to add border around image -->
<table align="center"><tr><td>
Screenshot of scan rate estimator
</td></tr></table>

## Viewing the bInterval field on the host PC

There are a lot of nested USB descriptors. The order is:

<!-- https://mermaid.js.org/syntax/flowchart.html#links-between-nodes -->
```mermaid
flowchart TD

device[Device descriptor]
config[Configuration descriptor]
interface[Interface descriptor]
endpoint[Endpoint descriptor]

device --> config
config --> interface
interface --> endpoint
```

The bInterval field is in the endpoint descriptor. See <https://beyondlogic.org/usbnutshell/usb5.shtml>.

### On Linux

On the command-line, use [`lsusb`](https://linux.die.net/man/8/lsusb) with the `--verbose` option.

Excerpted output:

<details>
<summary>Expand output from <code>lsusb</code></summary>

```text
Bus 001 Device 004: ID 1b4f:9206  
Device Descriptor:
  bLength                18
  bDescriptorType         1
  bcdUSB               2.00
  bDeviceClass          239 Miscellaneous Device
  bDeviceSubClass         2 ?
  bDeviceProtocol         1 Interface Association
  bMaxPacketSize0        64
  idVendor           0x1b4f 
  idProduct          0x9206 
  bcdDevice            1.00
  iManufacturer           1 SparkFun
  iProduct                2 SparkFun Pro Micro
  iSerial                 3 HIDPC
  bNumConfigurations      1
    ...
    Interface Descriptor:
      bLength                 9
      bDescriptorType         4
      bInterfaceNumber        2
      bAlternateSetting       0
      bNumEndpoints           1
      bInterfaceClass         3 Human Interface Device
      bInterfaceSubClass      0 No Subclass
      bInterfaceProtocol      0 None
      iInterface              0 
        HID Device Descriptor:
          bLength                 9
          bDescriptorType        33
          bcdHID               1.01
          bCountryCode            0 Not supported
          bNumDescriptors         1
          bDescriptorType        34 Report
          wDescriptorLength      47
         Report Descriptors: 
           ** UNAVAILABLE **
      Endpoint Descriptor:
        bLength                 7
        bDescriptorType         5
        bEndpointAddress     0x84  EP 4 IN
        bmAttributes            3
          Transfer Type            Interrupt
          Synch Type               None
          Usage Type               Data
        wMaxPacketSize     0x0040  1x 64 bytes
        bInterval               1
```

</details>

The last line shows `bInterval` is set to one.

For a GUI, use [usbview](http://www.kroah.com/linux-usb/) by Greg Kroah-Hartman:

Screenshot of Pro Micro in USBview

### On Windows

Use [USB Device Tree Viewer](https://www.uwe-sieber.de/usbtreeview_e.html) by Uwe Sieber. It is based on [USBView](https://learn.microsoft.com/en-us/windows-hardware/drivers/debugger/usbview?redirectedfrom=MSDN) in the Windows SDK.

Excerpted output:

<details>
<summary>Expand output from USB Device Tree Viewer</summary>

```text
      ========================== Summary =========================
Vendor ID                : 0x1B4F (Spark Fun Electronics)
Product ID               : 0x9206
USB Version              : 2.0 -> but Device is Full-Speed only
Port maximum Speed       : High-Speed (Companion Port 1-13 supports SuperSpeed)
Device maximum Speed     : Full-Speed
Device Connection Speed  : Full-Speed
Self powered             : no
Demanded Current         : 500 mA
Used Endpoints           : 5

      ======================== USB Device ========================

...

    ---------------------- Device Descriptor ----------------------
bLength                  : 0x12 (18 bytes)
bDescriptorType          : 0x01 (Device Descriptor)
bcdUSB                   : 0x200 (USB Version 2.0) -> but device is Full-Speed only
bDeviceClass             : 0xEF (Miscellaneous)
bDeviceSubClass          : 0x02
bDeviceProtocol          : 0x01 (IAD - Interface Association Descriptor)
bMaxPacketSize0          : 0x40 (64 bytes)
idVendor                 : 0x1B4F (Spark Fun Electronics)
idProduct                : 0x9206
bcdDevice                : 0x0100
iManufacturer            : 0x01 (String Descriptor 1)
 Language 0x0409         : "SparkFun"
iProduct                 : 0x02 (String Descriptor 2)
 Language 0x0409         : "SparkFun Pro Micro"
iSerialNumber            : 0x03 (String Descriptor 3)
 Language 0x0409         : "HIDPC"
bNumConfigurations       : 0x01 (1 Configuration)

...

        ---------------- Interface Descriptor -----------------
bLength                  : 0x09 (9 bytes)
bDescriptorType          : 0x04 (Interface Descriptor)
bInterfaceNumber         : 0x02 (Interface 2)
bAlternateSetting        : 0x00
bNumEndpoints            : 0x01 (1 Endpoint)
bInterfaceClass          : 0x03 (HID - Human Interface Device)
bInterfaceSubClass       : 0x00 (None)
bInterfaceProtocol       : 0x00 (None)
iInterface               : 0x00 (No String Descriptor)

        ------------------- HID Descriptor --------------------
bLength                  : 0x09 (9 bytes)
bDescriptorType          : 0x21 (HID Descriptor)
bcdHID                   : 0x0101 (HID Version 1.01)
bCountryCode             : 0x00 (00 = not localized)
bNumDescriptors          : 0x01
Descriptor 1:
bDescriptorType          : 0x22 (Class=Report)
wDescriptorLength        : 0x002F (47 bytes)
Error reading descriptor : ERROR_INVALID_PARAMETER

        ----------------- Endpoint Descriptor -----------------
bLength                  : 0x07 (7 bytes)
bDescriptorType          : 0x05 (Endpoint Descriptor)
bEndpointAddress         : 0x84 (Direction=IN EndpointID=4)
bmAttributes             : 0x03 (TransferType=Interrupt)
wMaxPacketSize           : 0x0040 (64 bytes)
bInterval                : 0x01 (1 ms)
```

</details>

The last line shows `bInterval` is set to one millisecond.

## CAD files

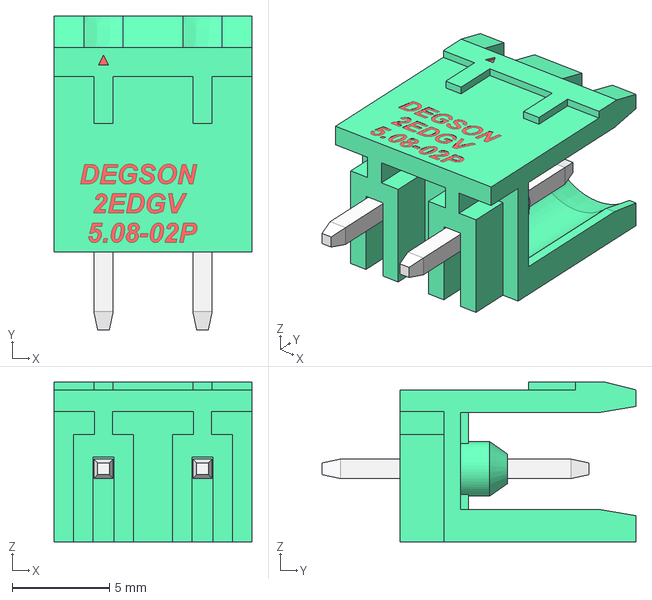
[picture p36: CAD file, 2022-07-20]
KiCad_project/3D models/2EDGV-5.08-02P-14-00AH_reduced_file_size.step
10.2 x 16.1 x 8.20 mm

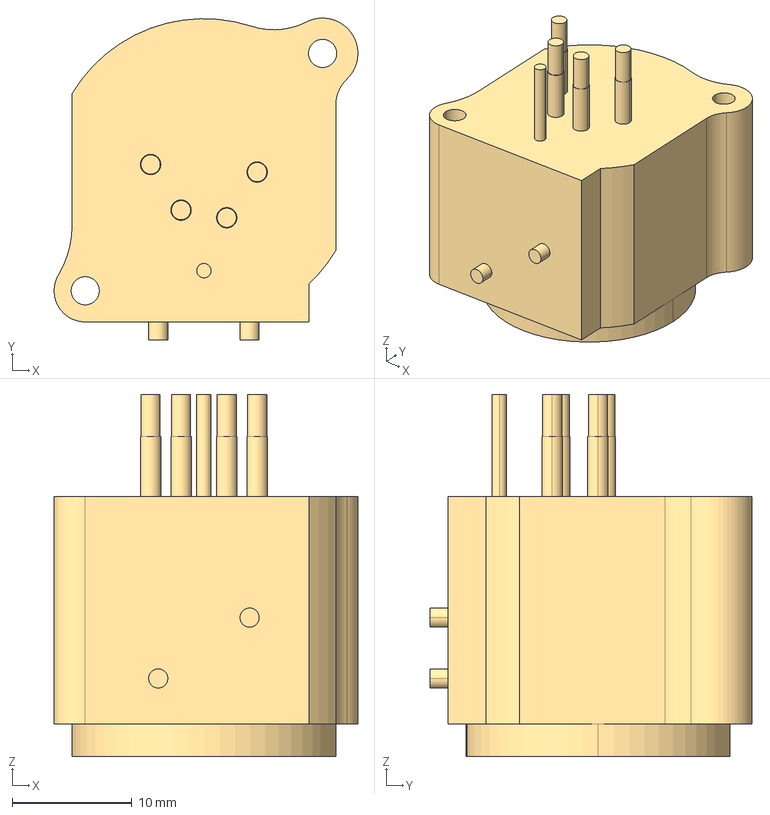
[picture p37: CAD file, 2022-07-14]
KiCad_project/3D models/Neutrik_NC4MBV.stp
25.3 x 26.8 x 30.2 mm

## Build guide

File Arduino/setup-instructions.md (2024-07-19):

# Setup instructions

These screenshots are from version 1.x of the Arduino software. For version 2.x, the steps are the same but the UI looks different.

## Set up the Arduino software

Install & launch the Arduino software and connect your Arduino board to your computer.

Next, follow the [Pro Micro Hookup Guide](https://learn.sparkfun.com/tutorials/pro-micro--fio-v3-hookup-guide#windows_boardaddon) to:

* edit Preferences in the Arduino software to add a URL to the "Additional Board Manager URLs", then
* install the board using the Boards Manager.

When finished, you should be able to select Tools > Board > SparkFun AVR Boards > SparkFun Pro Micro:

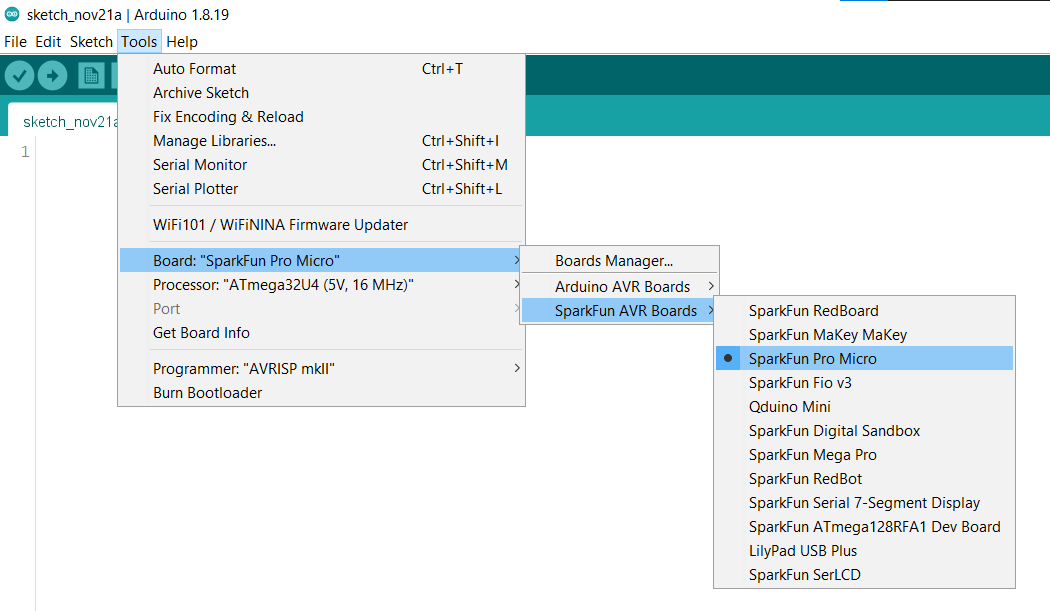
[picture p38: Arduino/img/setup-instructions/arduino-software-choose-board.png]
Screenshot of Arduino software with SparkFun AVR boards available


Once you select that board, the Tools menu will have another sub-menu called Processor:

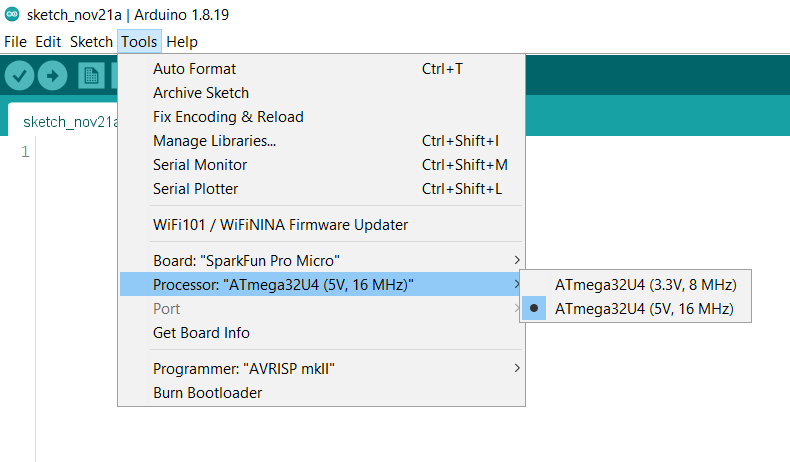
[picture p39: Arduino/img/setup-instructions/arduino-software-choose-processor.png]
Screenshot of Arduino software showing the menu to select the ATmega32U4 processor type


There are two options:

* If the clock speed is 16 MHz, then the voltage is 5 V.
* If the clock speed is 8 MHz, then the voltage is 3.3 V.

To tell which version you have, look for a relatively large shiny silver rectangle or oval on your Arduino board. That is the [crystal oscillator](https://en.wikipedia.org/wiki/Crystal_oscillator). The clock speed will be marked on top. To read the marking you will probably need to hold the board at an angle, and you might need magnification.

Here's what it looks like on the board I have:

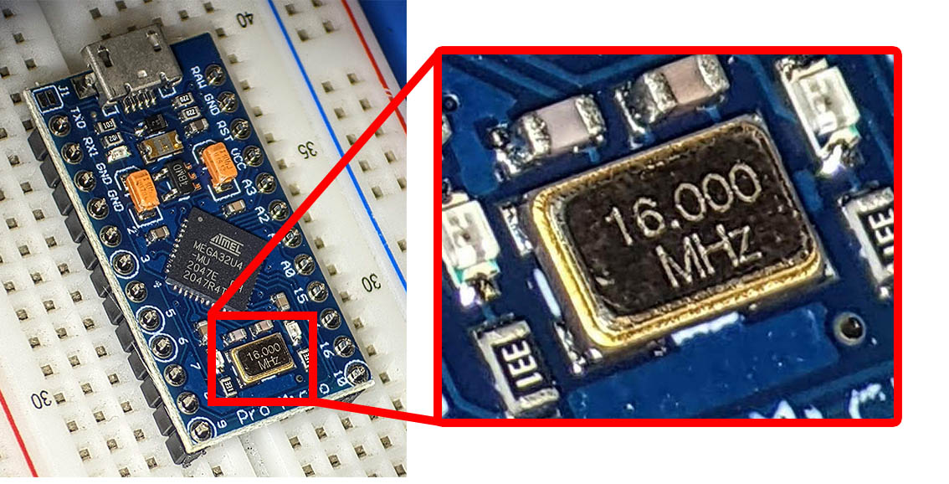
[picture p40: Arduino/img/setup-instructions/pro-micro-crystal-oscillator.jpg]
Photo illustration showing an Sparkfun Pro Micro with a close-up view of the crystal oscillator


You can also just try both processor options. Try uploading the [example Blinkies sketch](https://learn.sparkfun.com/tutorials/pro-micro--fio-v3-hookup-guide/example-1-blinkies) sketch. If the right processor is selected, the upload will finish in a few seconds. Otherwise, the upload will hang or fail and print weird errors. If that happens, unplug the USB cable connecting the Arduino board to your computer and the upload process wil immediately stop.

See the Arduino help page ['Error: avrdude' when uploading](https://support.arduino.cc/hc/en-us/articles/4401874331410--Error-avrdude-when-uploading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).

## Install the keyboard library

1. Click Tools > Manage Libraries.

1. Search for the Keyboard library, select the newest version, and install it:

    Screenshot of Keyboard library in Arduino Library Manager

    Link to documentation:

    * <https://www.arduino.cc/reference/en/language/functions/usb/keyboard/>

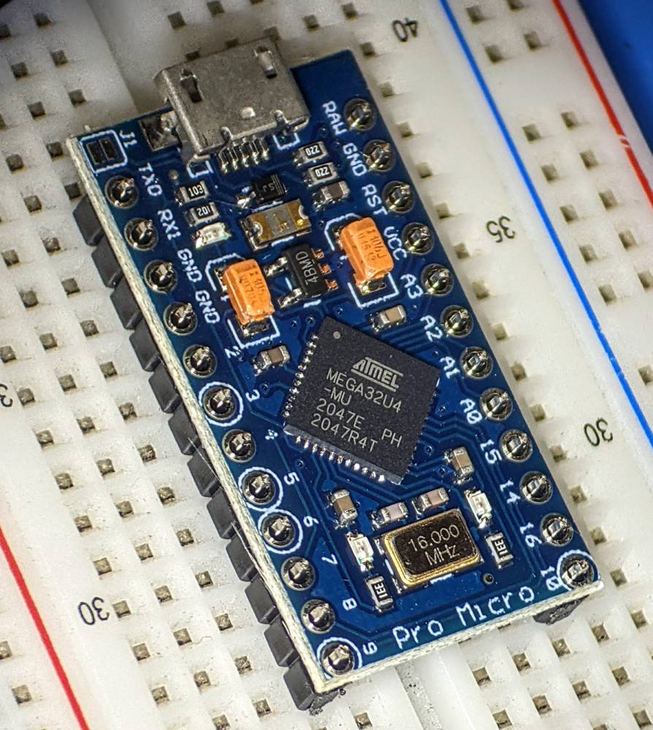
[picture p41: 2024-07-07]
Arduino/img/setup-instructions/arduino-pro-micro-16MHz.jpg

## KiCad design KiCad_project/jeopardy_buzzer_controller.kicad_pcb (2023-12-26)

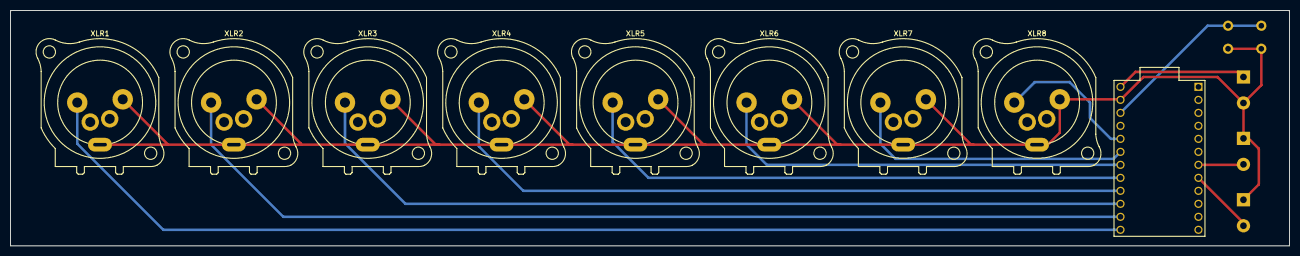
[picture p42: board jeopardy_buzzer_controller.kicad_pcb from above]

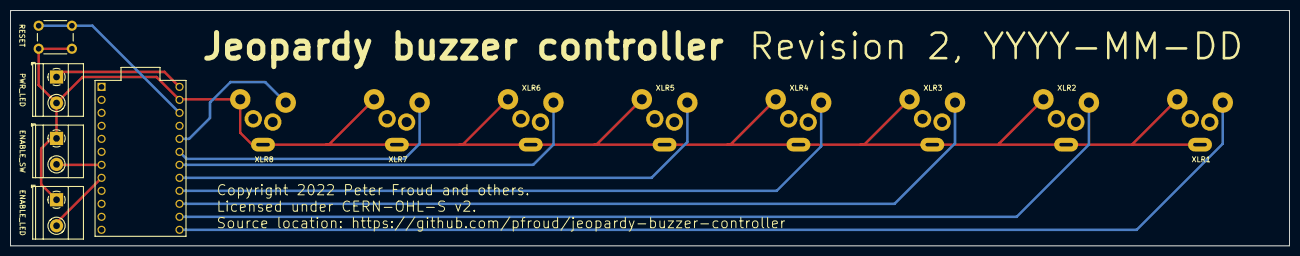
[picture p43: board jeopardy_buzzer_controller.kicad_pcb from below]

Board: 2 copper layers, 250.0 x 46.0 mm, 13 parts (5 on the bottom side), 13 nets.

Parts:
J11: ENABLE_SW; TerminalBlock_Phoenix_MKDS-1,5-2-5.08_1x02_P5.08mm_Horizont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
J12: ENABLE_LED; TerminalBlock_Phoenix_MKDS-1,5-2-5.08_1x02_P5.08mm_Horizont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
J13: PWR_LED; TerminalBlock_Phoenix_MKDS-1,5-2-5.08_1x02_P5.08mm_Horizont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
SW1: RESET; SW_PUSH_6mm
U1: Arduino Pro Micro; ProMicro
XLR1: XLR1; Jack_XLR_Neutrik_NC4MBV_Vertical_with_bigger_holes
XLR2: XLR2; Jack_XLR_Neutrik_NC4MBV_Vertical_with_bigger_holes
XLR3: XLR3; Jack_XLR_Neutrik_NC4MBV_Vertical_with_bigger_holes
XLR4: XLR4; Jack_XLR_Neutrik_NC4MBV_Vertical_with_bigger_holes
XLR5: XLR5; Jack_XLR_Neutrik_NC4MBV_Vertical_with_bigger_holes
XLR6: XLR6; Jack_XLR_Neutrik_NC4MBV_Vertical_with_bigger_holes
XLR7: XLR7; Jack_XLR_Neutrik_NC4MBV_Vertical_with_bigger_holes
XLR8: XLR8; Jack_XLR_Neutrik_NC4MBV_Vertical_with_bigger_holes

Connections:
/XLR1: U1.13 (B6), XLR1.1
/XLR2: U1.14 (B2), XLR2.1
/XLR3: U1.15 (B3), XLR3.1
/XLR4: U1.16 (B1), XLR4.1
/XLR5: U1.17 (F7), XLR5.1
/XLR6: U1.18 (F6), XLR6.1
/XLR7: U1.19 (F5), XLR7.1
/XLR8: U1.20 (F4), XLR8.1
GND: J11.1, J12.1, J13.2, SW1.2, U1.23 (GND), XLR1.4, XLR1.G, XLR2.4, XLR2.G, XLR3.4, XLR3.G, XLR4.4, XLR4.G, XLR5.4, XLR5.G, XLR6.4, XLR6.G, XLR7.4, XLR7.G, XLR8.4, XLR8.G
unnamed: J11.2, U1.7 (D4)
unnamed: J12.2, U1.8 (C6)
unnamed: J13.1, U1.24 (RAW)
unnamed: SW1.1, U1.22 (RST)

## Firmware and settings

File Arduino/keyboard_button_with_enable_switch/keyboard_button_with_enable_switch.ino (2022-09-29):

#include <Keyboard.h>

/*
               Arduino Pro Micro pinout

  Arduino   KiCad                    KiCad    Arduino
   pin      symbol                   symbol    pin
  number     pin     +---[USB]---+    pin     number
    1         1      |o         o|    24       RAW
    0         2      |o         o|    23       GND
  GND         3      |o         o|    22       RST
  GND         4      |o         o|    21       VCC
    2         5      |o         o|    20       21
    3         6      |o         o|    19       20
    4         7      |o         o|    18       19
    5         8      |o         o|    17       18
    6         9      |o         o|    16       15
    7        10      |o         o|    15       14
    8        11      |o         o|    14       16
    9        12      |o         o|    13       10
                     +-----------+
*/

#define PIN_INPUT_ENABLE_SWITCH 4 // Pin 7 on KiCad symbol is Arduino pin 4
#define PIN_OUTPUT_ENABLE_LIGHT 5 // Pin 8 on KiCad symbol is Arduino pin 5

#define DEBOUNCE_DELAY_MILLISEC 5 // only five milliseconds needed!

typedef struct {
  int arduinoPinNumber;
  char keyboardCharacter;
  bool isSoftwareKeyboardKeyDown;
  // stuff for debouncing is below
  int lastDigitalReading;
  unsigned long lastDebounceTimestamp;
} Channel;

#define CHANNEL_COUNT 8
Channel channels[] = {
  {10, '1', false, LOW, 0}, // Pin 13 on KiCad symbol is Arduino pin 10
  {16, '2', false, LOW, 0}, // Pin 14 on KiCad symbol is Arduino pin 16
  {14, '3', false, LOW, 0}, // Pin 15 on KiCad symbol is Arduino pin 14
  {15, '4', false, LOW, 0}, // Pin 16 on KiCad symbol is Arduino pin 15
  {18, '5', false, LOW, 0}, // Pin 17 on KiCad symbol is Arduino pin 18
  {19, '6', false, LOW, 0}, // Pin 18 on KiCad symbol is Arduino pin 19
  {20, '7', false, LOW, 0}, // Pin 19 on KiCad symbol is Arduino pin 20
  {21, '8', false, LOW, 0}  // Pin 20 on KiCad symbol is Arduino pin 21
};

bool needToReleaseKeysWhenDisabled = false;

void setup() {
  pinMode(PIN_INPUT_ENABLE_SWITCH, INPUT_PULLUP);
  pinMode(PIN_OUTPUT_ENABLE_LIGHT, OUTPUT);
  for (int i = 0; i < CHANNEL_COUNT; i++) {
    pinMode(channels[i].arduinoPinNumber, INPUT_PULLUP);
  }
  Keyboard.begin();
}


void loop() {

  // Inverted because using the Arduino's built-in pull-up resistor.
  const bool isEnabled = digitalRead(PIN_INPUT_ENABLE_SWITCH) == LOW;

  if (isEnabled) {
    digitalWrite(PIN_OUTPUT_ENABLE_LIGHT, HIGH);
    needToReleaseKeysWhenDisabled = true;
    doKeyboardStuff();
  } else {
    digitalWrite(PIN_OUTPUT_ENABLE_LIGHT, LOW);
    if (needToReleaseKeysWhenDisabled) {
      releaseKeys();
    }
    needToReleaseKeysWhenDisabled = false;
  }

}

void doKeyboardStuff() {
  for (int i = 0; i < CHANNEL_COUNT; i++) {

    // Inverted because using the Arduino's built-in pull-up resistor.
    const bool presentDigitalReading = digitalRead(channels[i].arduinoPinNumber) == LOW;

    /*
      Debouncing code is from the build-in Arduino example.
      Accessable in the Arduino software from File > Examples > 02.Digital > Debounce
      Also online at https://docs.arduino.cc/built-in-examples/digital/Debounce
    */

    if (presentDigitalReading != channels[i].lastDigitalReading) {
      channels[i].lastDebounceTimestamp = millis();
    }

    if ((millis() - channels[i].lastDebounceTimestamp) > DEBOUNCE_DELAY_MILLISEC) {
      // The present reading has been there for longer than the debounce delay.

      if (presentDigitalReading != channels[i].isSoftwareKeyboardKeyDown) {
        if (presentDigitalReading) {
          Keyboard.press(channels[i].keyboardCharacter);
        } else {
          Keyboard.release(channels[i].keyboardCharacter);
        }
        channels[i].isSoftwareKeyboardKeyDown = presentDigitalReading;
      }
    }

    channels[i].lastDigitalReading = presentDigitalReading;
  }

}

void releaseKeys() {
  for (int i = 0; i < CHANNEL_COUNT; i++) {
    if (channels[i].isSoftwareKeyboardKeyDown) {
      Keyboard.release(channels[i].keyboardCharacter);
      channels[i].isSoftwareKeyboardKeyDown = false;
    }
  }
}

/*
  Copyright Peter Froud 2022.

  This source describes Open Hardware and is licensed under the CERN-OHL-S v2.

  You may redistribute and modify this source and make products using it under
  the terms of the CERN-OHL-S v2 (https://ohwr.org/cern_ohl_s_v2.txt).

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
  Source location: https://github.com/pfroud/jeopardy-buzzer-controller
*/

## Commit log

2022-07-20 Add power LED, enable switch, enable LED
    [jeopardy_buzzer_controller.kicad_pcb, jeopardy_buzzer_controller.kicad_sch]
2022-07-20 Add 3D model of pluggable screw terminal block
    [2EDGV-5.08-02P-14-00AH_reduced_file_size.step, jeopardy_buzzer_controller.kicad_pcb]
2022-07-20 Move Arduino Pro Micro library to Git submodule
2022-07-20 Move 3D models to subfolder
    [2EDGV-5.08-02P-14-00AH_reduced_file_size.step, Neutrik_NC4MBV.stp]
2022-07-20 Update links to 3D models
    [jeopardy_buzzer_controller.kicad_pcb]
2022-07-31 Add arduino sketch
2022-07-31 Got Arduino sketch working
2022-08-08 Add enable light to arduino sketch
2022-08-15 Figured out sensible layout for everything
    [jeopardy_buzzer_controller.kicad_pcb]
2022-08-15 Route tracks
    [jeopardy_buzzer_controller.kicad_pcb]
2022-08-15 Clean up silkscreen
    [jeopardy_buzzer_controller.kicad_pcb]
2022-08-15 Add CERN OHL2-S license
    [jeopardy_buzzer_controller.kicad_pcb, jeopardy_buzzer_controller.kicad_sch]
2022-08-15 Add title text w/ revision number and date
    [jeopardy_buzzer_controller.kicad_pcb]
2022-08-15 Move KiCad project into own directory
    [2EDGV-5.08-02P-14-00AH_reduced_file_size.step, Neutrik_NC4MBV.stp, jeopardy_buzzer_controller.kicad_pcb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]
2022-08-15 Put Arduino Kicad library back in as git submodule
2022-08-19 Vertically center XLR connectors in downspout
    [jeopardy_buzzer_controller.kicad_pcb, jeopardy_buzzer_controller.kicad_sch]
2022-08-23 Add date stamp and generate gerbers!
    [jeopardy_buzzer_controller.kicad_pcb]
2022-09-06 Increase font size and thickness
    [jeopardy_buzzer_controller.kicad_pcb]
2022-09-06 Add custom XLR footprint with bigger holes
    Adding a modified version of the "Jack_XLR_Neutrik_NC4MBV_Vertical"
    footprint included in the KiCad "Connector_Audio" library.
    The NC4MBV footprint included with KiCad uses hole sizes specified by
    Neutrik here: https://www.neutrik.com/en/product/nc4mbv-1
    Pins 1 through 4 are cylindrical, with a double-taper on the tip
    and then a shoulder. The ground pin is rectangular with a shoulder only.
    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
    [jeopardy_buzzer_controller.kicad_pcb, jeopardy_buzzer_controller.kicad_sch]
2022-09-06 Fix silkscreen intersecting pad
    [jeopardy_buzzer_controller.kicad_pcb]
2022-09-07 Fix pin mapping between KiCad and Arduino
    [jeopardy_buzzer_controller.kicad_sch]
2022-09-28 Add debug printing to serial
2022-09-29 Add lots of debugging printouts
2022-09-29 Remove printouts, shorten debounce delay to 5 ms
    [keyboard_button_with_enable_switch.ino]
2023-04-08 Add screenshots of kicad schematic
2023-12-26 Remove dimensions of unused enclosure from PCB
    [jeopardy_buzzer_controller.kicad_pcb]
2024-07-07 Fix case-sensitive path
2024-07-07 Fix more case-sensitive file paths
2024-07-31 Rename directory of screws for XLR connectors
2024-11-03 Add heading for schematic screenshots
2024-11-22 Add docs about XLR connector footprint

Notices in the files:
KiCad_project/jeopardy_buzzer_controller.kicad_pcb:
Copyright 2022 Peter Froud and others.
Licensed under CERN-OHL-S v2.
